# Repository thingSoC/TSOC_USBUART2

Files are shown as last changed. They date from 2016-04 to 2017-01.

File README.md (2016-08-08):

# TSOC_USBUART2

The thingSoC USBUART2 Base board incorporates a Cypress CY7C65215 Dual Channel USB Bridge, that supports UART, I2C, SPI, and JTAG interfaces in a thingSoC format.

The thingSoC USBUART2 Base board has two USB bridge channels, which can be programmed to be either UART, I2C, SPI, JTAG, or Capacitance Sensing (buttons/sliders) Human Input devices.

USB Bridge One (Port 1) is connected to an FTDI pinout compatible programming connector, while USB Bridge Two (Port 2) is connected to the thingSoC standard UART channel.

Port1 can be used to program a target microprocessor, at the same time Port2 is used for another purpose (i.e. debug channel, USB to RS-485 bridge, etc).  

It's like having two (2) FTDI adapters in One!

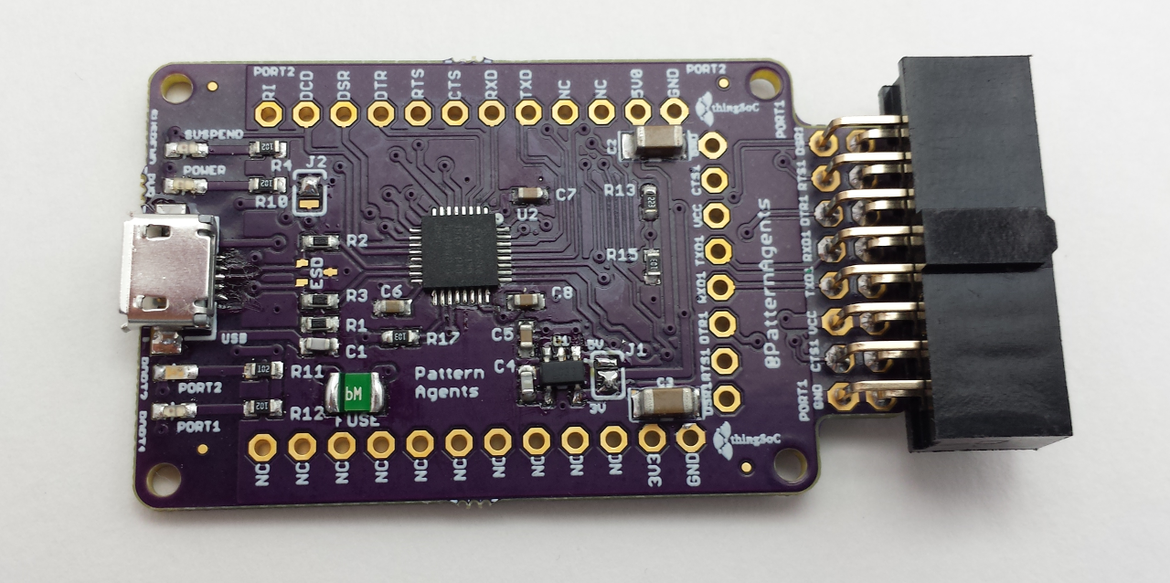
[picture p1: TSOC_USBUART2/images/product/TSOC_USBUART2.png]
thingSoC TSOC_USBUART2
[ 
TSOC_USBUART2](https://github.com/thingSoC/TSOC_USBUART2)

The thingSoC Digital Programming Connector (DPC) is backward compatible with 
the industry standard six (6) pin "FTDI" pinout USB to Serial Adapter pinout.
However, the thingSoC Digital Programming Connector (DPC) includes 
two(2) extra pins (RTS & DEBUG) for extended device programming, 
such as "NodeMCU types" which use the RTS signal as a programming Enable,
and the DTR signal as a programming Reset.

---------------------------------------
## Use it as a Programming Dongle

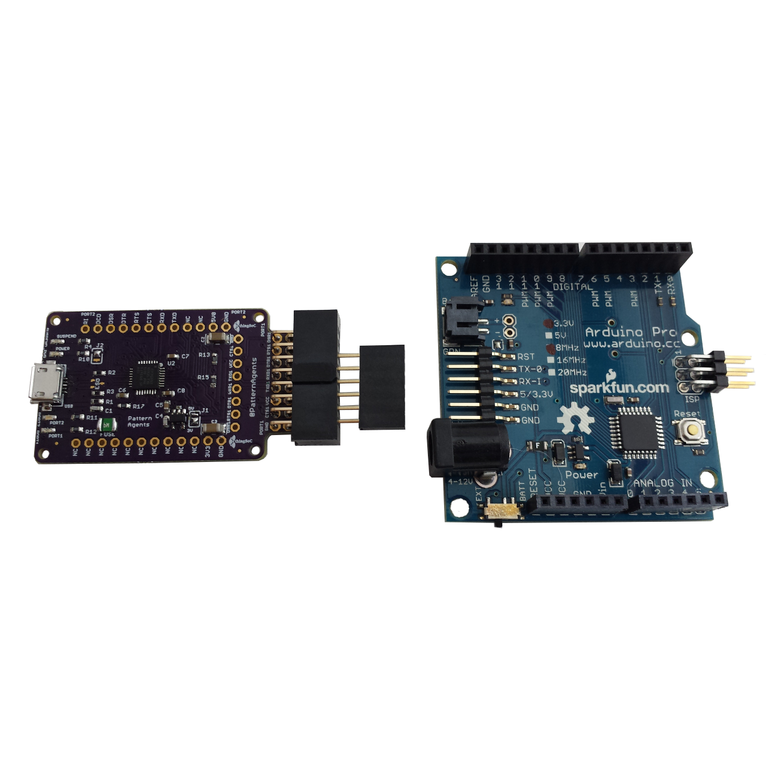
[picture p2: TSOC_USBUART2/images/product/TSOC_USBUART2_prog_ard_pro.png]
thingSoC TSOC_USBUART2
[ 
TSOC_USBUART2 to FTDI Six (6) Pin : Programming an Arduino Pro](https://github.com/thingSoC/TSOC_USBUART2)

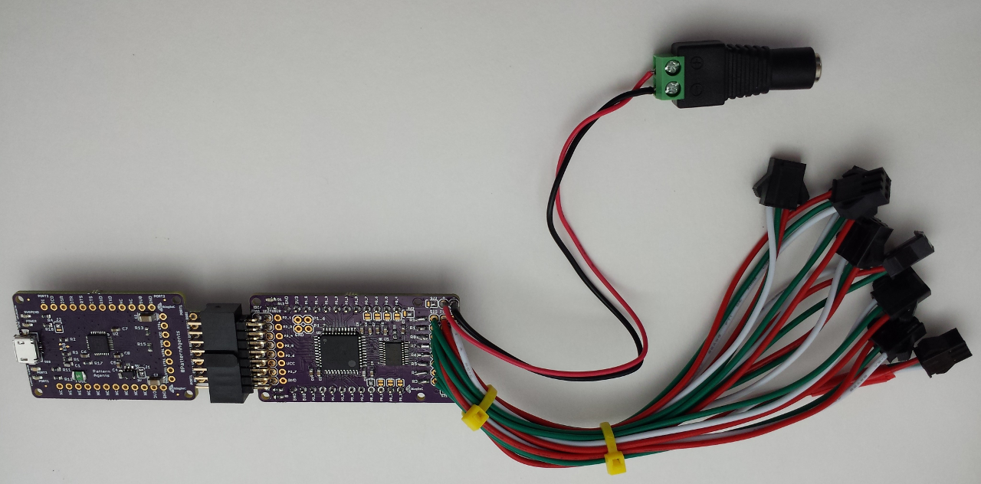
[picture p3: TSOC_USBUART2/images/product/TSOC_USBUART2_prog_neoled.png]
thingSoC TSOC_USBUART2
[ 
Programming a TSOC_NeoLED Board](https://github.com/thingSoC/TSOC_USBUART2)

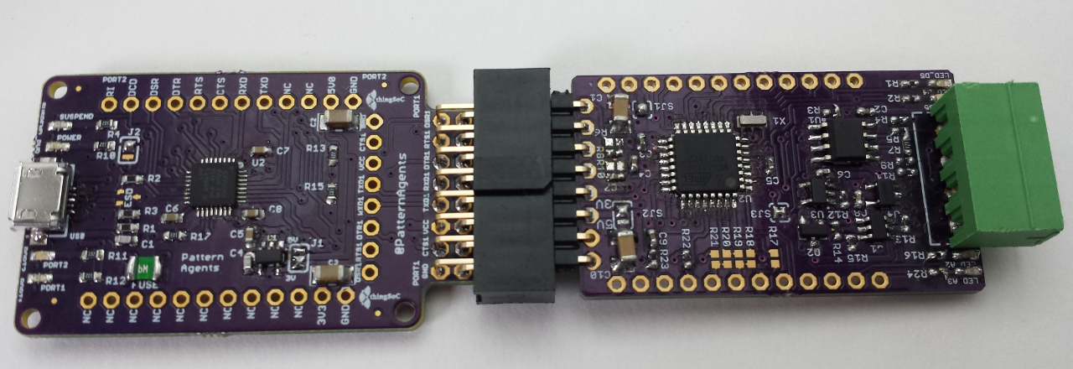
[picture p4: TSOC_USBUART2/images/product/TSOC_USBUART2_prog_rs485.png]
thingSoC TSOC_USBUART2
[ 
Programming a TSOC_RS485 Board](https://github.com/thingSoC/TSOC_USBUART2)

---------------------------------------
## Use it as a Protocol Adapter

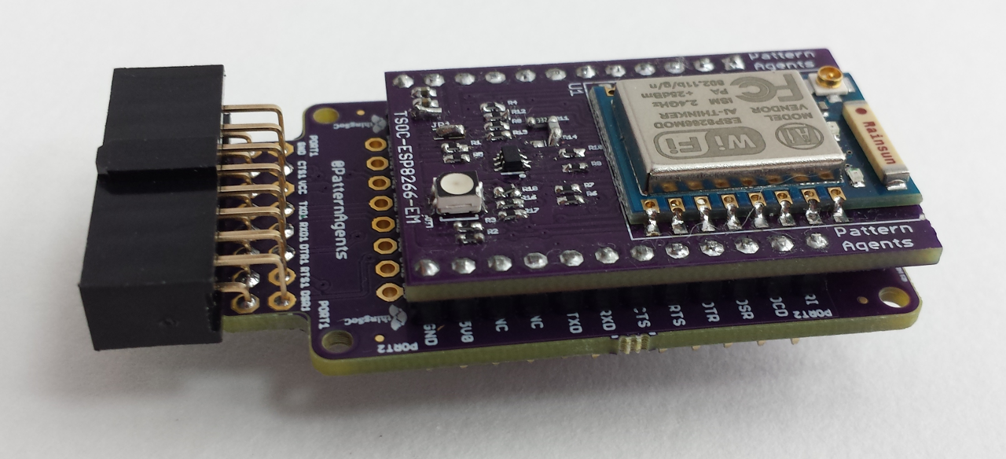
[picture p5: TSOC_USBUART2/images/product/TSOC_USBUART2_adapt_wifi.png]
thingSoC TSOC_USBUART2
[ 
USB to WiFi Adapter](https://github.com/thingSoC/TSOC_USBUART2)

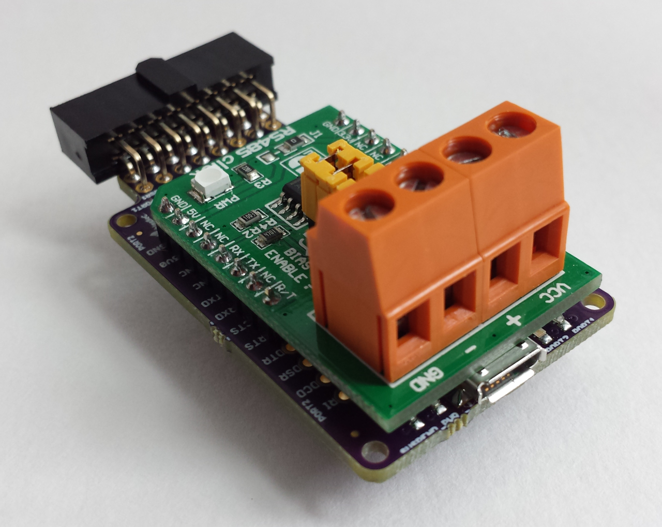
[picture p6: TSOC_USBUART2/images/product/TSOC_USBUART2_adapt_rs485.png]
thingSoC TSOC_USBUART2
[ 
USB to RS-485 Adapter](https://github.com/thingSoC/TSOC_USBUART2)

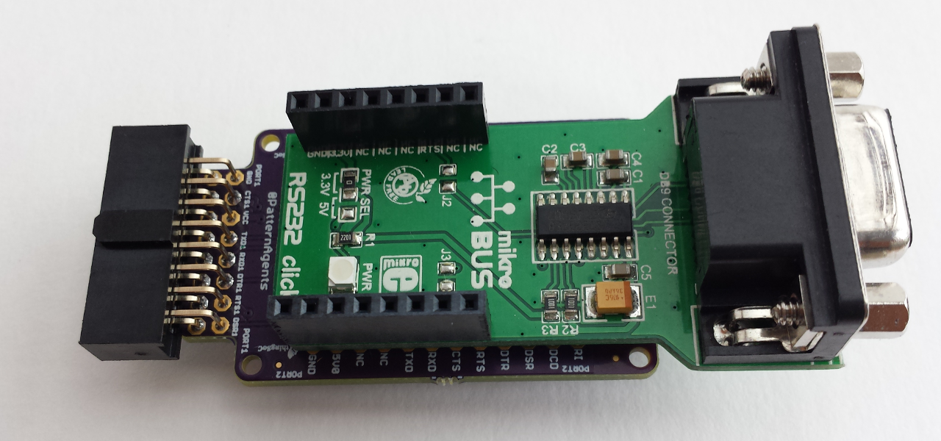
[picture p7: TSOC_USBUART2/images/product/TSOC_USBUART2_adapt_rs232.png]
thingSoC TSOC_USBUART2
[ 
USB to RS-232 Adapter](https://github.com/thingSoC/TSOC_USBUART2)

---------------------------------------
## TSOC_USBUART2 Model Images

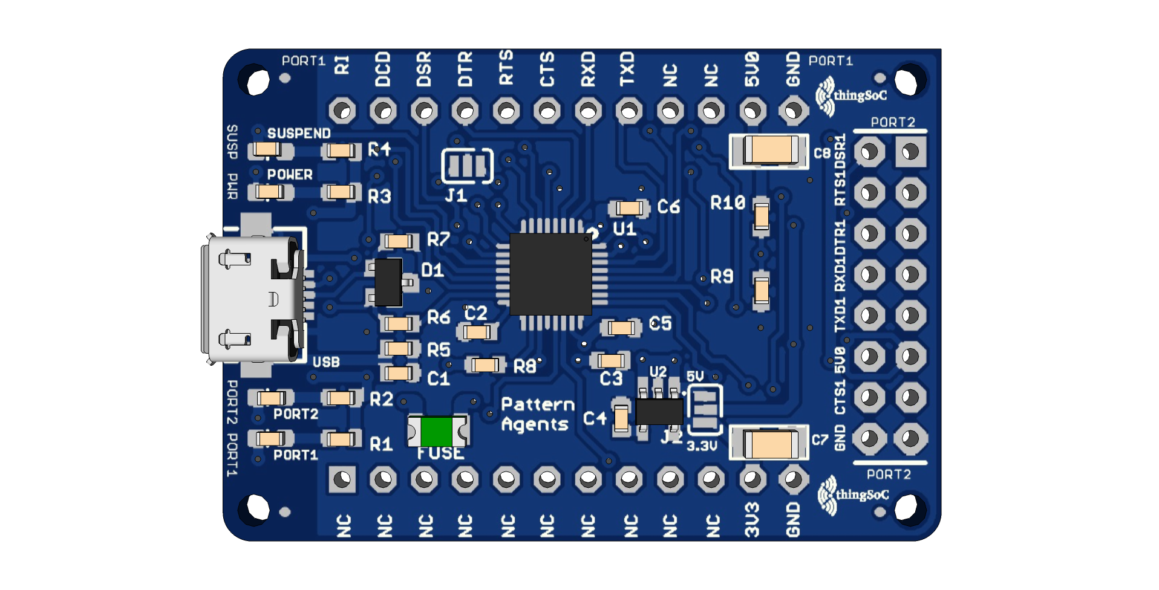
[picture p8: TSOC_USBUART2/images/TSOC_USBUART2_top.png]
thingSoC TSOC_USBUART2
[ 
TSOC_USBUART2](https://github.com/thingSoC/TSOC_USBUART2)

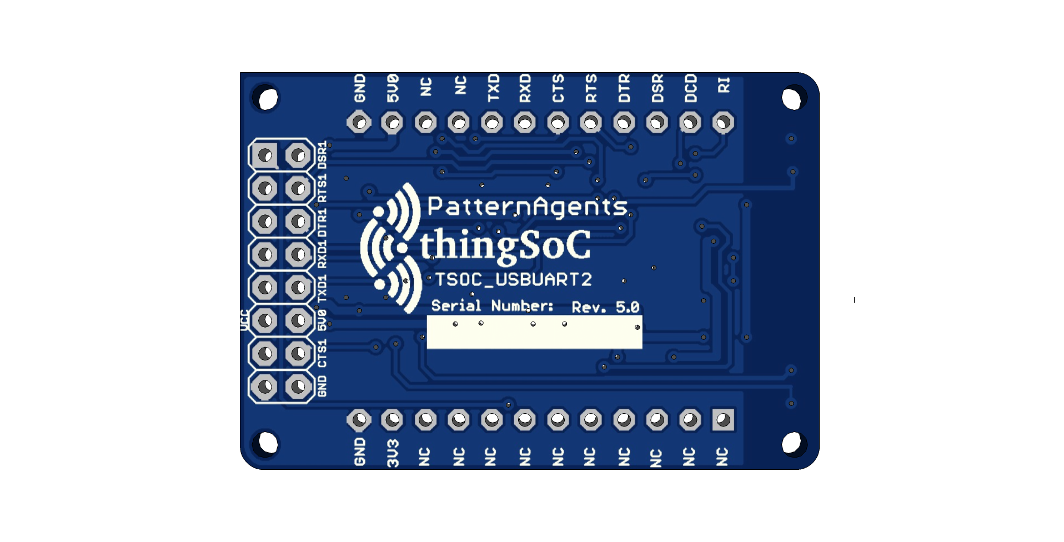
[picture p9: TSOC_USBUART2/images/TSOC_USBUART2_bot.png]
thingSoC TSOC_USBUART2
[ 
TSOC_USBUART2](https://github.com/thingSoC/TSOC_USBUART2)

---------------------------------------

## TSOC_USBUART2 Status <a name="TSOC_USBUART2_status"/>

Revision 1.0 - New Layout with Dual USB to UART device

Revision 2.0 - New PCB Outline, update to thingSoC Revision 2.0 

Revision 4.0 - New DPC connector, fix spacing.

Revision 4.1 - Update silkscreen, add more legends

---------------------------------------

## TSOC_USBUART2 Documentation Index <a name="TSOC_USBUART2_documentation_index"/>

[TSOC_USBUART2 Project](https://github.com/thingSoC/TSOC_USBUART2/)

[TSOC_USBUART2 Hardware](https://github.com/thingSoC/TSOC_USBUART2/tree/master/TSOC_USBUART2/hardware)

---------------------------------------

## thingSoC Documentation Index <a name="thingSoC_documentation_index"/>

[thingSoC Organization Website](http://thingSoC.github.io)

[thingSoC FAQ - Frequently Asked Questions](http://thingsoc.github.io/support/faq.html)

---------------------------------------

[thingSoC 
*thingSoC*](http://thingsoc.github.io)

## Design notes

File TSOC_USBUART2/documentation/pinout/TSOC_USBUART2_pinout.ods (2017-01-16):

 |  |  |  |  |  |  | USB
DEFAULT | PORT | ADC | PWM |  |  |  |  |  |  |  |  | DEFAULT | PORT | PWM | LEGEND
 |  |  |  |  |  |  |  |  |  |  |  |  |  |  | POWER/GROUND PINS
IO2 | NC |  |  |  |  |  |  |  |  |  |  | RI1 |  |  | DIGITAL PINS
IO1 | NC |  |  |  |  |  |  |  |  |  |  | DCD1 |  |  | ANALOG/ADC PINS
SS2 | NC |  |  |  |  |  |  |  |  |  |  | DSR1 |  |  | PWM PINS
SS1 | NC |  |  |  |  |  |  |  |  |  |  | DTR1 |  |  | TOUCH PINS
IRQ | NC |  |  |  |  |  |  |  |  |  |  | RTS1 |  |  | UART PINS
ATN | NC |  |  |  |  |  |  |  |  |  |  | CTS1 |  |  | JTAG/DEBUG PINS
SSEL | NC |  |  |  |  |  |  |  |  |  |  | RXD1 |  |  | I2C BUS PINS
SCK | NC |  |  |  |  |  |  |  |  |  |  | TXD1 |  |  | SPI BUS PINS
MISO | NC |  |  |  |  |  |  |  |  |  |  | NC
MOSI | NC |  |  |  |  |  |  |  |  |  |  | NC
3.3 VOLTS | 3V3 |  |  |  |  |  |  |  |  |  |  | 5.0 VOLTS | 5V0
GROUND | GND |  |  |  |  |  |  |  |  |  |  | GND | GND
 |  |  |  | DSR2 | RTS2 | DTR2 | TXD2 | RXD2 | 5V0 | CTS2 | GND |  |  | PatternAgents thingSoC USBUART2
 |  |  |  | NC | NC | NC | NC | NC | VCC | NC | GND |  |  | http://github.com/thingsoc/usbuart2

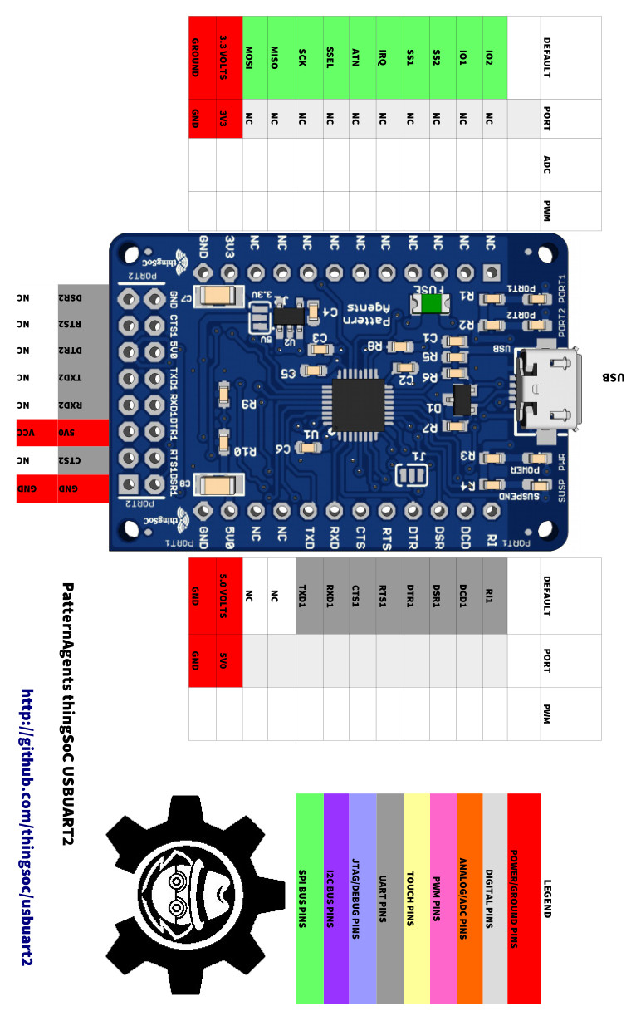
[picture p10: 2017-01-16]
TSOC_USBUART2/documentation/pinout/TSOC_USBUART2_pinout_long.jpg

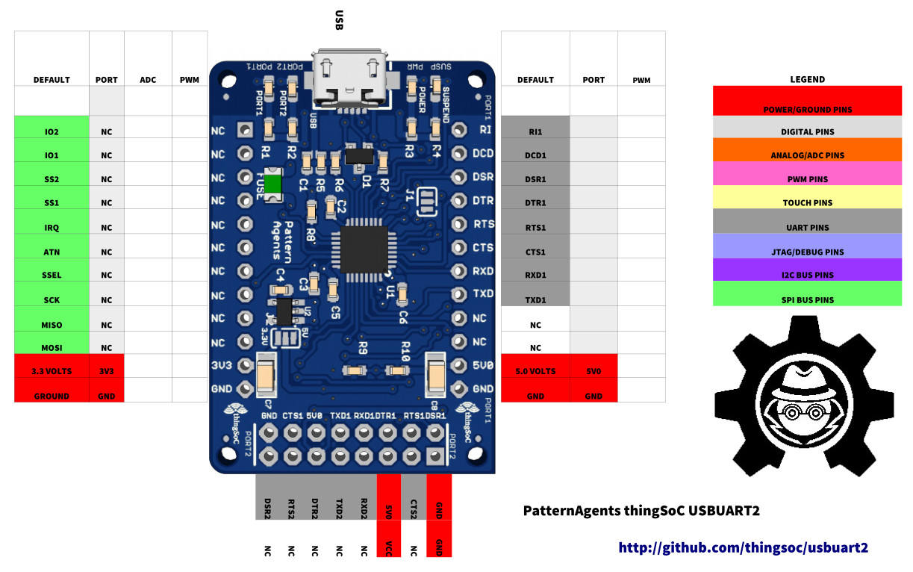
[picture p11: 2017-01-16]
TSOC_USBUART2/documentation/pinout/TSOC_USBUART2_pinout.jpg

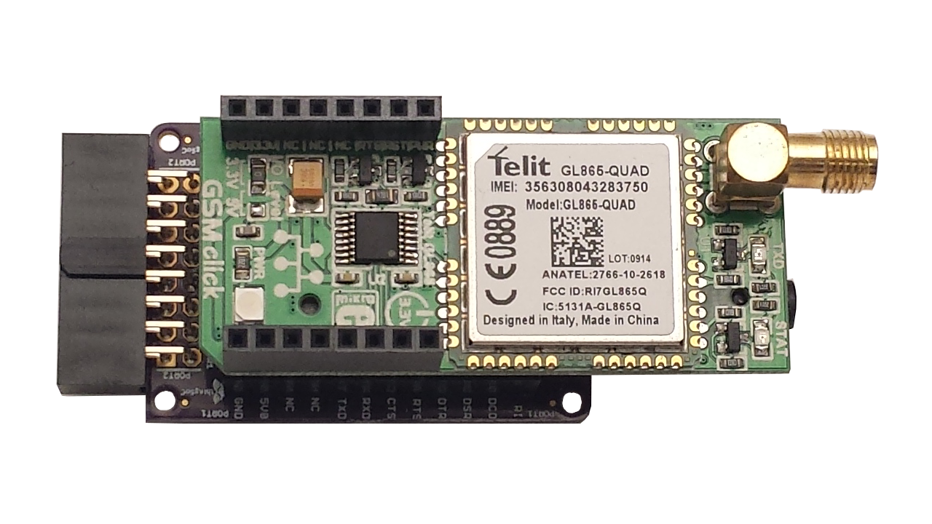
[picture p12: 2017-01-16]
TSOC_USBUART2/images/product/TSOC_USBUART2_with_GSM.png

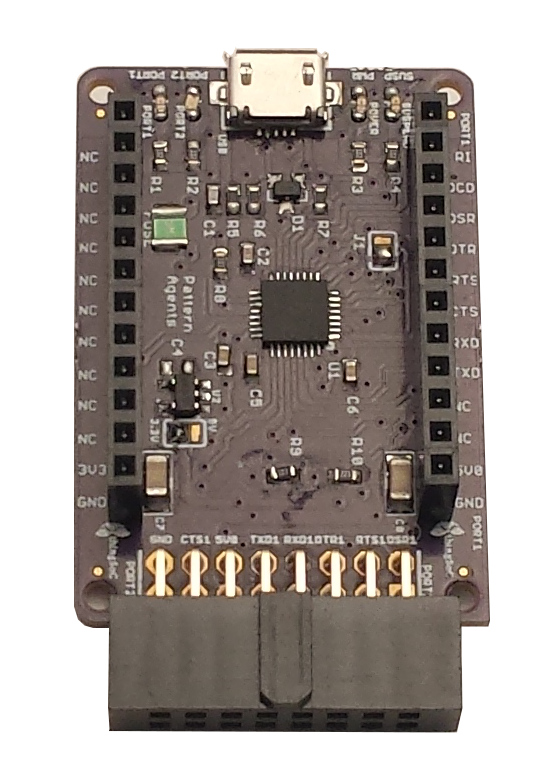
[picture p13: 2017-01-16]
TSOC_USBUART2/images/product/TSOC_UART_top_pop_vert.jpg

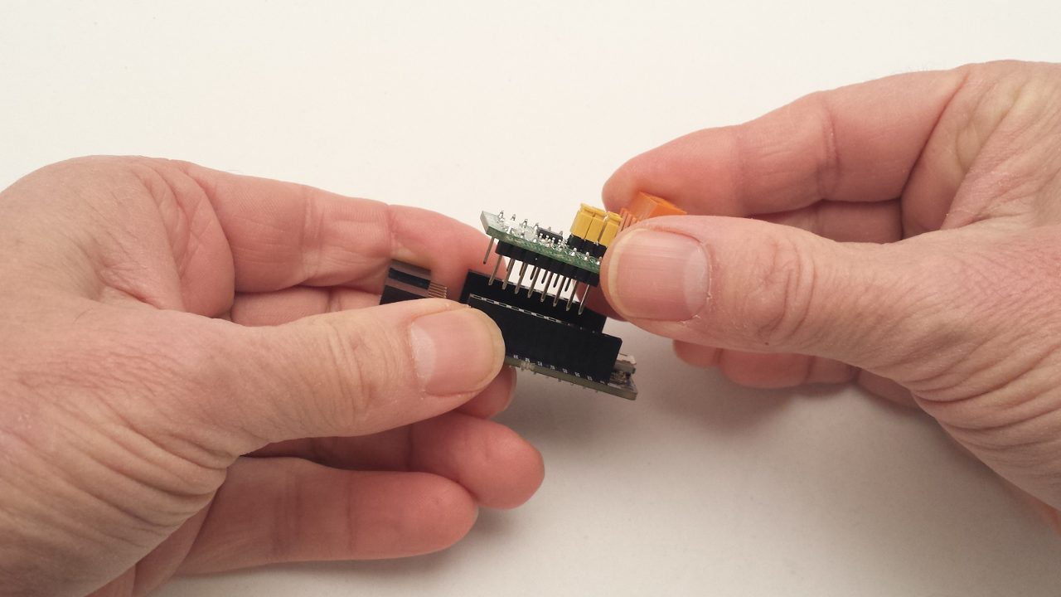
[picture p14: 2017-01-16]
TSOC_USBUART2/images/product/TSOC_USBUART2_adapt_rs485_insert.png

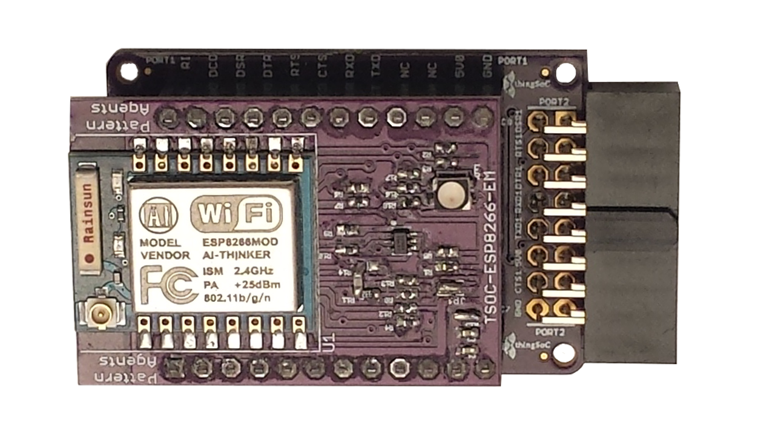
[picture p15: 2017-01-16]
TSOC_USBUART2/images/product/TSOC_USBUART2_with_ESP8266.png

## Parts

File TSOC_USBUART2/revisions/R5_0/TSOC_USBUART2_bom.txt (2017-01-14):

Partlist exported from U:/PatternAgents/eagle/TSOC_Modules/TSOC_USBUART2/TSOC_USBUART2/revisions/R5_0/TSOC_USBUART2.sch at 12/18/2016 3:53:13 PM

Part    Value              Device                         Package          Description                                                                                                   
C1      470pF              CAP-0603                       EIA-0603         Ceramic Capacitor SMD                                                                                         
C2      1.0uF              CAP-0603                       EIA-0603         Ceramic Capacitor SMD                                                                                         
C3      0.1uF              CAP-0603                       EIA-0603         Ceramic Capacitor SMD                                                                                         
C4      470pF              CAP-0603                       EIA-0603         Ceramic Capacitor SMD                                                                                         
C5      0.1uF              CAP-0603                       EIA-0603         Ceramic Capacitor SMD                                                                                         
C6      0.1uF              CAP-0603                       EIA-0603         Ceramic Capacitor SMD                                                                                         
C7      22uF               CAP-1206                       EIA-1206         Ceramic Capacitor SMD                                                                                         
C8      22uF               CAP-1206                       EIA-1206         Ceramic Capacitor SMD                                                                                         
D1      5V-225MW           SMD-DIODE-TVS-5V-225MW(SOT-23) SOT-23           304050003                                                                                                     
DPC                        M08X2                          2X8              .1" headers, two rows of 8 each                                                                               
FUSE    500mA-PTC          PTCSMD                         PTC-1206         Resettable Fuse PTC                                                                                           
PORT1   YELLOW             LED0603                        LED-0603         LEDs                                                                                                          
PORT2   BLUE               LED0603                        LED-0603         LEDs                                                                                                          
POWER   GRN                LED0603                        LED-0603         LEDs                                                                                                          
R1      1K                 RESISTOR-0603                  EIA-0603                                                                                                                       
R2      1K                 RESISTOR-0603                  EIA-0603                                                                                                                       
R3      1K                 RESISTOR-0603                  EIA-0603                                                                                                                       
R4      1K                 RESISTOR-0603                  EIA-0603                                                                                                                       
R5      1M                 RESISTOR-0603                  EIA-0603                                                                                                                       
R6      22                 RESISTOR-0603                  EIA-0603                                                                                                                       
R7      22                 RESISTOR-0603                  EIA-0603                                                                                                                       
R8      10K                RESISTOR-0603                  EIA-0603                                                                                                                       
R9      10K                RESISTOR-0603                  EIA-0603                                                                                                                       
R10     22K                RESISTOR-0603                  EIA-0603                                                                                                                       
SUSPEND RED                LED0603                        LED-0603         LEDs                                                                                                          
U1      CY7C65215-32-PROTO CY7C65215-32-PROTO             QFN32-PROTO      Cypress EZ-USB ® CY7C65215-32QFN                                       
U2      MIC5219 3.3V       V_REG_MIC52193.3V              SOT23-5          V_REG MIC5219                                                                                                 
USB     USB_AB             USB_AB                         USB-AB-MICRO-SMD USB

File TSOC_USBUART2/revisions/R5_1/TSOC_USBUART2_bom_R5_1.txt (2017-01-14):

Partlist exported from U:/PatternAgents/eagle/TSOC_Modules/TSOC_USBUART2/TSOC_USBUART2/revisions/R5_1/TSOC_USBUART2_R5_1.sch at 12/27/2016 11:35:59 AM

Qty Value              Device                          Package          Parts                  Description                                                                                                   
1   100pf              CERAMIC-100PF-50V-5%-NPO(0603)  C0603            C1                     302010076                                                                                                     
1   1uf                CERAMIC-1UF-25V-10%-X7R(0603)   C0603            C2                     302010139                                                                                                     
1   DNP                CAP-0603                        EIA-0603         C4                     Ceramic Capacitor SMD                                                                                         
3   100nf              CERAMIC-100NF-50V-10%-X7R(0603) C0603            C3, C5, C6             302010138                                                                                                     
2   22uf               TANTALUM-SMD-22UF-10V(AVX-A)    AVX-A            C7, C8                 302020008                                                                                                     
4   1K                 SMD-RES-1K-1%-1/10W(0603)       R0603            R1, R2, R3, R4         301010298                                                                                                     
1   1M                 SMD-RES-1M-1%-1/10W(0603)       R0603            R5                     301010151                                                                                                     
2   22R                SMD-RES-22R-5%-1/10W(0603)      R0603            R6, R7                 301010289                                                                                                     
2   10K                SMD-RES-10K-1%-1/10W(0603)      R0603            R8, R9                 301010299                                                                                                     
1   22K                SMD-RES-22K-5%-1/10W(0603)      R0603            R10                    301010132                                                                                                     
1   5V-225MW           SMD-DIODE-TVS-5V-225MW(SOT-23)  SOT-23           ESD                    304050003                                                                                                     
1   AP2112K-3.3V       V_REG_LDOSMD                    SOT23-5          U3                     Voltage Regulator LDO                                                                                         
1   BLUE-0603          SMD-LED-CLEAR-BLUE(0603)        LED-0603         D2                     304090045                                                                                                     
1   CY7C65215-32-PROTO CY7C65215-32-PROTO              QFN32-PROTO      U1                     Cypress EZ-USB ® CY7C65215-32QFN DUAL CHANNEL USB TO UART/SPI/IC Bridge                                       
1   GREEN-0603         SMD-LED-CLEAR-GREEN(0603)       LED-0603         D3                     304090043                                                                                                     
1   RED-0603           LED-SMD-RED-DIFFUSED(0603)      LED-0603         D4                     304090042                                                                                                     
1   SMD1206R500SF      SMD-PPTC-500MA(1206)            F1206            FUSE                   307010002                                                                                                     
1   USB_AB             USB_AB                          USB-AB-MICRO-SMD USB                     
1   YELLOW-0603        SMD-LED-CLEAR-YELLOW(0603)      LED-0603         D1                     304090044

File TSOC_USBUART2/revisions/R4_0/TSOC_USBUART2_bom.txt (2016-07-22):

Partlist exported from U:/PatternAgents/eagle/TSOC_Modules/TSOC_USBUART2/TSOC_USBUART2/TSOC_USBUART2.sch at 7/11/2016 12:24:20 PM

Qty Value              Device             Package              Parts                  Description                      Digikey              MPN
1   CY7C65215-32-PROTO CY7C65215-32-PROTO QFN32-PROTO          U2                     CY7C65215-32QFN
1   MIC5219 3.3V       V_REG_MIC52193.3V  SOT23-5              U1                     MIC5219
1   SP1001-02JTG       SP1001-02JTG       SC70-3               ESD                    TVS Diode Array
1   USB_AB             USB_AB             USB-AB-MICRO-SMD     USB                    USB-AB-MICRO-SMD
1   M08X02             M08X2              2X8                  J3                     .1" headers, Male, Shrouded, RA  ED10535-ND           On-Shore-Technology-Inc. 302-R161
2   M12                M12                1X12F                TSOC1, TSOC2           .1" headers, Female              S6100-ND               PPTC121LFBN-RC
1   M08                M08                1X08F                TSOC3                  .1" headers, Female              S7006-ND               PPTC081LFBN-RC
1   RED                LED0603            LED-0603             SUSPEND                LED
1   BLUE               LED0603            LED-0603             TXD                    LED
1   GRN                LED0603            LED-0603             POWER                  LED
1   YELLOW             LED0603            LED-0603             RXD                    LED
1   500mA-PTC          PTCSMD             PTC-1206             FUSE                   Fuse PPTC (0.5A @ 15v)
3   0.1uF              CAP-0603           EIA-0603             C5, C7, C8             Capacitor SMD
1   1.0uF              CAP-0603           EIA-0603             C6                     Capacitor SMD
2   10K                RESISTOR-0603      EIA-0603             R15, R17               Resistor SMD
4   1K                 RESISTOR-0603      EIA-0603             R4, R10, R11, R12      Resistor SMD
1   1M                 RESISTOR-0603      EIA-0603             R1                     Resistor SMD
2   22                 RESISTOR-0603      EIA-0603             R2, R3                 Resistor SMD
1   22K                RESISTOR-0603      EIA-0603             R13                    Resistor SMD
2   22uF               CAP-1206           EIA-1206             C2, C3                 Capacitor SMD
2   470pF              CAP-0603           EIA-0603             C1, C4                 Capacitor SMD

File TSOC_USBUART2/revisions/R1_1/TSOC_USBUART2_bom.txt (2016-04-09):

Partlist exported from /home/moxon/github/TSOC-USBUART2/TSOC-USBUART2/TSOC_USBUART2.sch at 4/9/16 11:58 AM
Qty Value              Device             Package          Parts                  Description
1   RED                LED0603            LED-0603         SUSPEND                LEDs                                                            
1   GRN                LED0603            LED-0603         POWER                  LEDs                                                                 
1   BLUE               LED0603            LED-0603         TXD                    LEDs                          
1   YELLOW             LED0603            LED-0603         RXD                    LEDs
3   0.1uF              CAP-0603           EIA-0603         C5, C7, C8             Ceramic Capacitor SMD
1   1.0uF              CAP-0603           EIA-0603         C6                     Ceramic Capacitor SMD
2   10K                RESISTOR-0603      EIA-0603         R15, R17                                   
1   1A                 FUSE               EIA-0603         F1                     Resettable PPTC Fuse - 0603 Footptint
4   1K                 RESISTOR-0603      EIA-0603         R4, R10, R11, R12                                          
1   1M                 RESISTOR-0603      EIA-0603         R1                                                        
2   22                 RESISTOR-0603      EIA-0603         R2, R3                                                   
1   22K                RESISTOR-0603      EIA-0603         R13                                                     
2   22uF               CAP-1206           EIA-1206         C2, C3                 Ceramic Capacitor SMD           
2   470pF              CAP-0603           EIA-0603         C1, C4                 Ceramic Capacitor SMD          
1   CY7C65215-32-PROTO CY7C65215-32-PROTO QFN32-PROTO      U2                     Cypress EZ-USB ® CY7C65215-32QFN DUAL CHANNEL USB TO UART/SPI/IC Bridge
1   M08                M08                1X08-SMD-FEMALE  P1                                                                                        
1   M08PTH             M08PTH             1X08             P1A                                                                                      
1   MIC5219 3.3V       V_REG_MIC52193.3V  SOT23-5          U1                     V_REG MIC5219                                                    
1   SP1001-02JTG       SP1001-02JTG       SC70-3           ESD                    Littelfuse SP1001-02JTG TVS Diode Array 8pf 15kV 
1   USB_AB             USB_AB             USB-AB-MICRO-SMD USB                    USB AB connector

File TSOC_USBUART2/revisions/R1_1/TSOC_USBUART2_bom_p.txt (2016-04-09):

Partlist exported from /home/moxon/github/TSOC-USBUART2/TSOC-USBUART2/TSOC_USBUART2.sch at 4/9/16 11:56 AM

Part    Value              Device             Package          Description                                                                                                                                                                               
C1      470pF              CAP-0603           EIA-0603         Ceramic Capacitor SMD                                                                                                                                                                     
C2      22uF               CAP-1206           EIA-1206         Ceramic Capacitor SMD                                                                                                                                                                     
C3      22uF               CAP-1206           EIA-1206         Ceramic Capacitor SMD                                                                                                                                                                     
C4      470pF              CAP-0603           EIA-0603         Ceramic Capacitor SMD                                                                                                                                                                     
C5      0.1uF              CAP-0603           EIA-0603         Ceramic Capacitor SMD                                                                                                                                                                     
C6      1.0uF              CAP-0603           EIA-0603         Ceramic Capacitor SMD                                                                                                                                                                     
C7      0.1uF              CAP-0603           EIA-0603         Ceramic Capacitor SMD                                                                                                                                                                     
C8      0.1uF              CAP-0603           EIA-0603         Ceramic Capacitor SMD                                                                                                                                                                     
ESD     SP1001-02JTG       SP1001-02JTG       SC70-3           Littelfuse SP1001-02JTG 
F1      1A                 FUSE               EIA-0603         Resettable PPTC Fuse - 0603 Footptint                                                                                                                                                                                                                                                                                                                 
J1      JMP-3-1_2          JMP-3-1_2          JMP-3-1_2        Three Terminal Jumper - 1 & 2 Connected                                                                                                                                                   
J2      JMP-3-1_2          JMP-3-1_2          JMP-3-1_2        Three Terminal Jumper - 1 & 2 Connected                                                                                                                                                   
P1      M08                M08                1X08-SMD-FEMALE                                                                                                                                                                                            
P1A     M08PTH             M08PTH             1X08                                                                                                                                                                                                       
POWER   GRN                LED0603            LED-0603         LEDs                                                                                                                                                                                      
R1      1M                 RESISTOR-0603      EIA-0603                                                                                                                                                                                                   
R2      22                 RESISTOR-0603      EIA-0603                                                                                                                                                                                                   
R3      22                 RESISTOR-0603      EIA-0603                                                                                                                                                                                                   
R4      1K                 RESISTOR-0603      EIA-0603                                                                                                                                                                                                   
R10     1K                 RESISTOR-0603      EIA-0603                                                                                                                                                                                                   
R11     1K                 RESISTOR-0603      EIA-0603                                                                                                                                                                                                   
R12     1K                 RESISTOR-0603      EIA-0603                                                                                                                                                                                                   
R13     22K                RESISTOR-0603      EIA-0603                                                                                                                                                                                                   
R15     10K                RESISTOR-0603      EIA-0603                                                                                                                                                                                                   
R17     10K                RESISTOR-0603      EIA-0603                                                                                                                                                                                                   
RXD     YELLOW             LED0603            LED-0603         LEDs                                                                                                                                                                                      
SUSPEND RED                LED0603            LED-0603         LEDs                                                                                                                                                                                                                                                                                                                                             
TXD     BLUE               LED0603            LED-0603         LEDs                                                                                                                                                                                      
U1      MIC5219 3.3V       V_REG_MIC52193.3V  SOT23-5          V_REG MIC5219                                                                                                                                                                             
U2      CY7C65215-32-PROTO CY7C65215-32-PROTO QFN32-PROTO      Cypress EZ-USB ® CY7C65215-32QFN DUAL CHANNEL USB TO UART/SPI/IC Bridge                                                                                                                   
USB     USB_AB             USB_AB             USB-AB-MICRO-SMD USB AB connector

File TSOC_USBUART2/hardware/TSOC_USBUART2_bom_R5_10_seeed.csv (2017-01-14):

Part/Designator | Manufacture Part Number/Seeed SKU | Quantity
C1, C2, C3, C4, C6, C7 | 302010138 | 6
R8, R9, R10, R11 | 301010299 | 4
R1 | 301010298 | 1
R2, R3, R4, R5, R6, R7, R12, R13, R14, R15 | 301010124 | 10
C5 | 302010013 | 1
I2C1, I2C2, I2C3, I2C4 | 320110034 | 4
I2CS | "320110033" | 1
J1 | 320020079 | 1
U1 | PCA9546APWR | 1
D1 | 304090043 | 1

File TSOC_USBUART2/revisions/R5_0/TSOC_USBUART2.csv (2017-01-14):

Part | Value | Device | Package | Description
$$U$2 | TSOC-LOGO | TSOC-LOGO | TSOC-LOGO-BLANK | thingSoC Logo
C1 | 470pF | CAP-0603 | EIA-0603 | Ceramic Capacitor SMD
C2 | 1.0uF | CAP-0603 | EIA-0603 | Ceramic Capacitor SMD
C3 | 0.1uF | CAP-0603 | EIA-0603 | Ceramic Capacitor SMD
C4 | 470pF | CAP-0603 | EIA-0603 | Ceramic Capacitor SMD
C5 | 0.1uF | CAP-0603 | EIA-0603 | Ceramic Capacitor SMD
C6 | 0.1uF | CAP-0603 | EIA-0603 | Ceramic Capacitor SMD
C7 | 22uF | CAP-1206 | EIA-1206 | Ceramic Capacitor SMD
C8 | 22uF | CAP-1206 | EIA-1206 | Ceramic Capacitor SMD
D1 | 5V-225MW | SMD-DIODE-TVS-5V-225MW(SOT-23) | SOT-23 | 304050003
DPC |  | M08X2 | 2X8 | .1 headers, two rows of 8 each"
FID1 | FIDUCIALUFIDUCIAL | FIDUCIALUFIDUCIAL | MICRO-FIDUCIAL | Fiducial Alignment Points
FID2 | FIDUCIALUFIDUCIAL | FIDUCIALUFIDUCIAL | MICRO-FIDUCIAL | Fiducial Alignment Points
FID3 | FIDUCIALUFIDUCIAL | FIDUCIALUFIDUCIAL | MICRO-FIDUCIAL | Fiducial Alignment Points
FID4 | FIDUCIALUFIDUCIAL | FIDUCIALUFIDUCIAL | MICRO-FIDUCIAL | Fiducial Alignment Points
FUSE | 500mA-PTC | PTCSMD | PTC-1206 | Resettable Fuse PTC
J1 | JMP-3-1_2 | JMP-3-1_2 | JMP-3-1_2 | Three Terminal Jumper - 1 & 2 Connected
J2 | JMP-3-1_2 | JMP-3-1_2 | JMP-3-1_2 | Three Terminal Jumper - 1 & 2 Connected
PORT1 | YELLOW | LED0603 | LED-0603 | LEDs
PORT2 | BLUE | LED0603 | LED-0603 | LEDs
POWER | GRN | LED0603 | LED-0603 | LEDs
R1 | 1K | RESISTOR-0603 | EIA-0603
R2 | 1K | RESISTOR-0603 | EIA-0603
R3 | 1K | RESISTOR-0603 | EIA-0603
R4 | 1K | RESISTOR-0603 | EIA-0603
R5 | 1M | RESISTOR-0603 | EIA-0603
R6 | 22 | RESISTOR-0603 | EIA-0603
R7 | 22 | RESISTOR-0603 | EIA-0603
R8 | 10K | RESISTOR-0603 | EIA-0603
R9 | 10K | RESISTOR-0603 | EIA-0603
R10 | 22K | RESISTOR-0603 | EIA-0603
SUSPEND | RED | LED0603 | LED-0603 | LEDs
TSOC | TSOC-24-BB | TSOC-24-BB | TSOC-BB-S24 | thingSoC Twenty-Four(24) Pin Socket
U$1 | TSOC-LOGO | TSOC-LOGO | TSOC-LOGO-BLANK | thingSoC Logo
U$3 | TSOC-LOGO | TSOC-LOGO | TSOC-LOGO-BLANK | thingSoC Logo
U$4 | TSOC-PCB-SINGLE | TSOC-PCB-SINGLE | TSOC-BB-BRD-DIM | thingSoC PCB Outlines
U$6 | TSOC-LOGO-SMALL | TSOC-LOGO-SMALL | TSOC-LOGO-SML | thingSoC Logo
U$100 | TSOC-LOGO-LRG | TSOC-LOGO-LRG | TSOC-LOGO-LRG | thingSoC Logo
U1 | CY7C65215-32-PROTO | CY7C65215-32-PROTO | QFN32-PROTO | Cypress EZ-USB ® CY7C65215-32QFN DUAL CHANNEL USB TO UART/SPI/IC Bridge
U2 | MIC5219 3.3V | V_REG_MIC52193.3V | SOT23-5 | V_REG MIC5219
USB | USB_AB | USB_AB | USB-AB-MICRO-SMD | This is a USB AB connector that is compatible with USB OTG. i.e. this connector can serve as a host or device

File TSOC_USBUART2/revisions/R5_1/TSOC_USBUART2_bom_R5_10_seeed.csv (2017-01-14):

Part/Designator | Manufacture Part Number/Seeed SKU | Quantity
C1 | 302010076 | 1
C2 | 302010139 | 1
C3, C5, C6 | 302010138 | 3
C7,C8 | 302020008 | 2
R1, R2, R3, R4 | 301010298 | 4
R5 | 301010151 | 1
R6, R7 | 301010289 | 2
R8, R9 | 301010299 | 2
R10 | 301010132 | 1
U1 | CY7C65215A-32LTXI | 1
U2 | AP2112K-3.3TRG1 | 1
D1 | 304090044 | 1
D2 | 304090045 | 1
D3 | 304090043 | 1
D4 | 304090042 | 1
ESD | 304050003 | 1
FUSE | 307010002 | 1
USB | 10104111-0001LF | 1
PORT1L, PORT1R | PPTC121LFBN-RC | 2
PORT2 | SFH11-PBPC-D08-RA-BK | 1

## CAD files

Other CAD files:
TSOC_USBUART2/eagleUp/TSOC_USBUART2.skp

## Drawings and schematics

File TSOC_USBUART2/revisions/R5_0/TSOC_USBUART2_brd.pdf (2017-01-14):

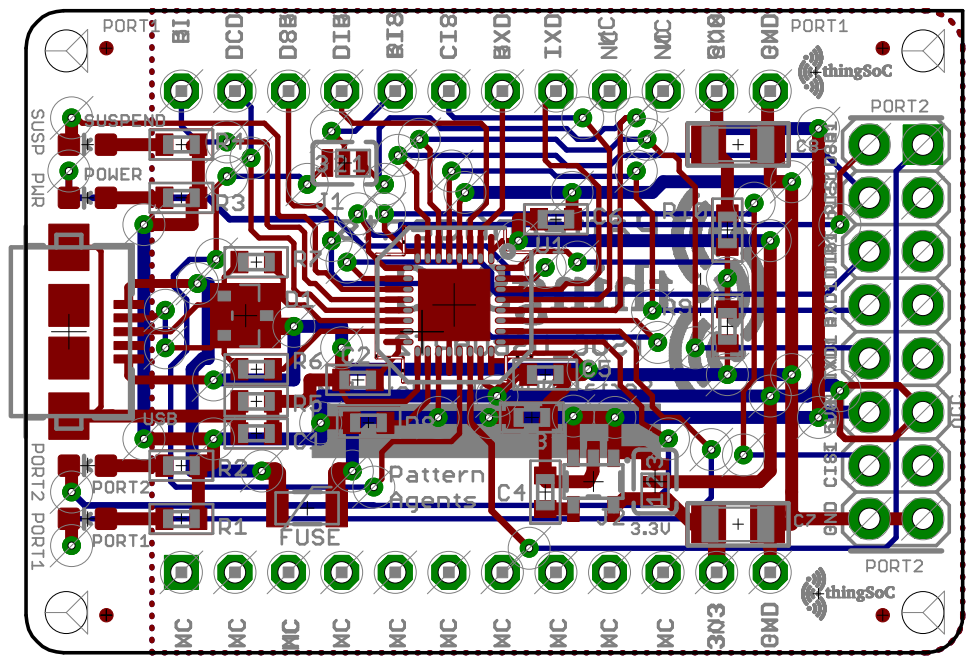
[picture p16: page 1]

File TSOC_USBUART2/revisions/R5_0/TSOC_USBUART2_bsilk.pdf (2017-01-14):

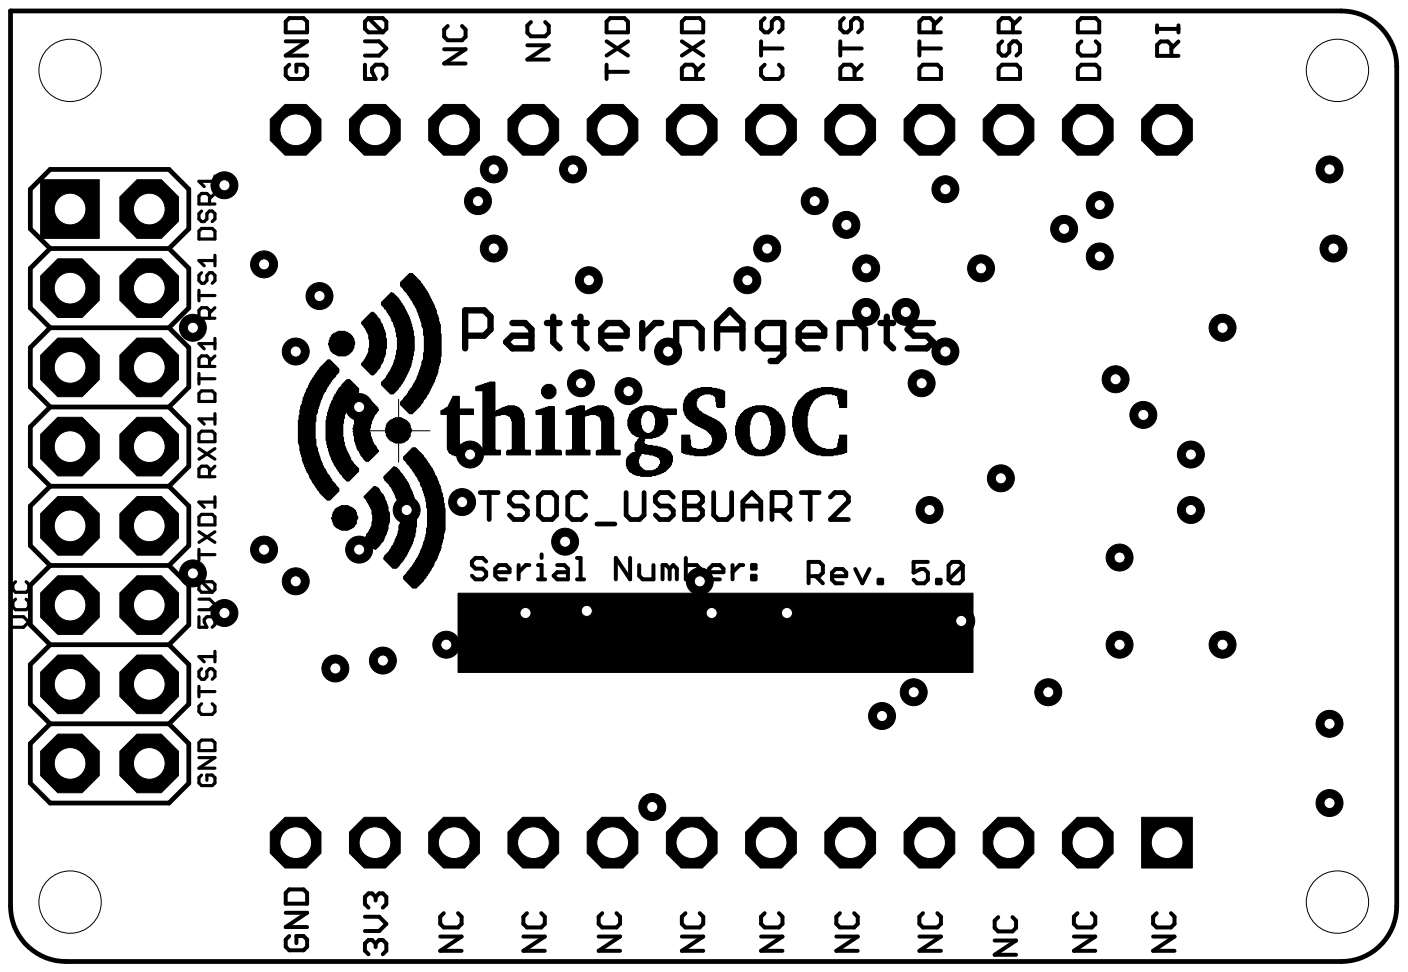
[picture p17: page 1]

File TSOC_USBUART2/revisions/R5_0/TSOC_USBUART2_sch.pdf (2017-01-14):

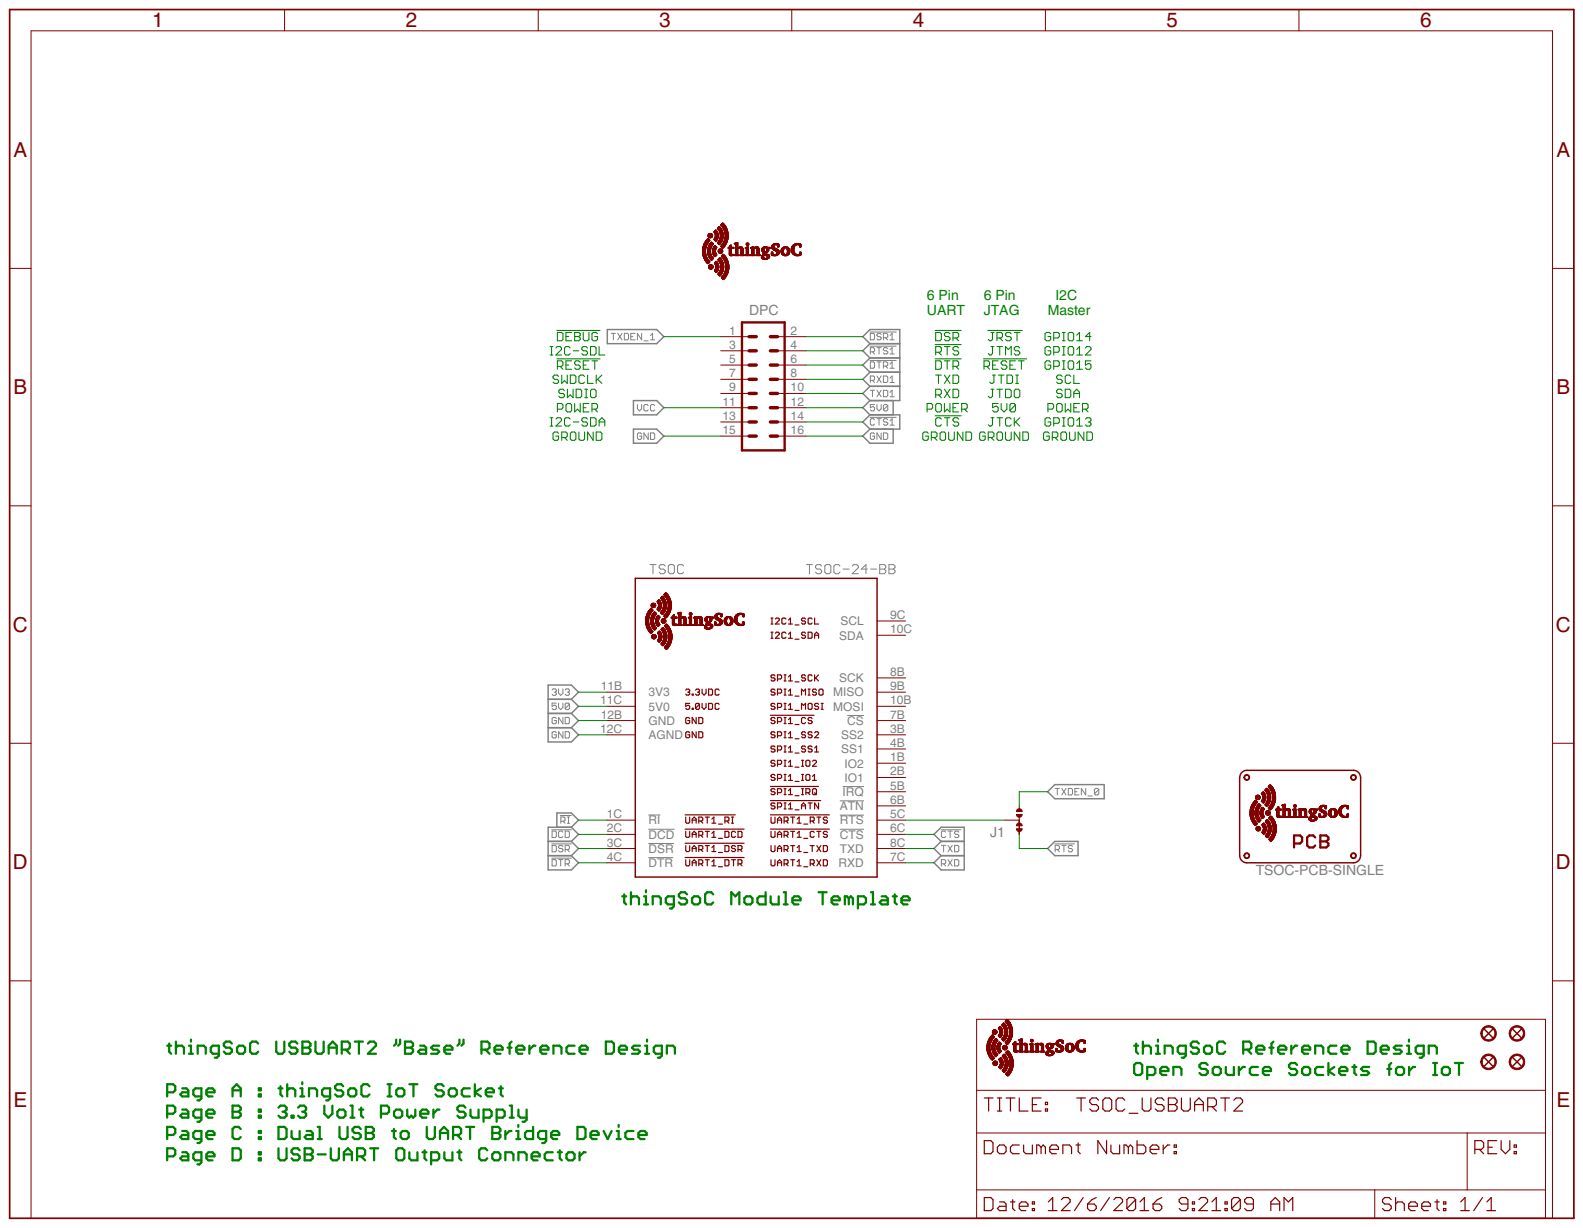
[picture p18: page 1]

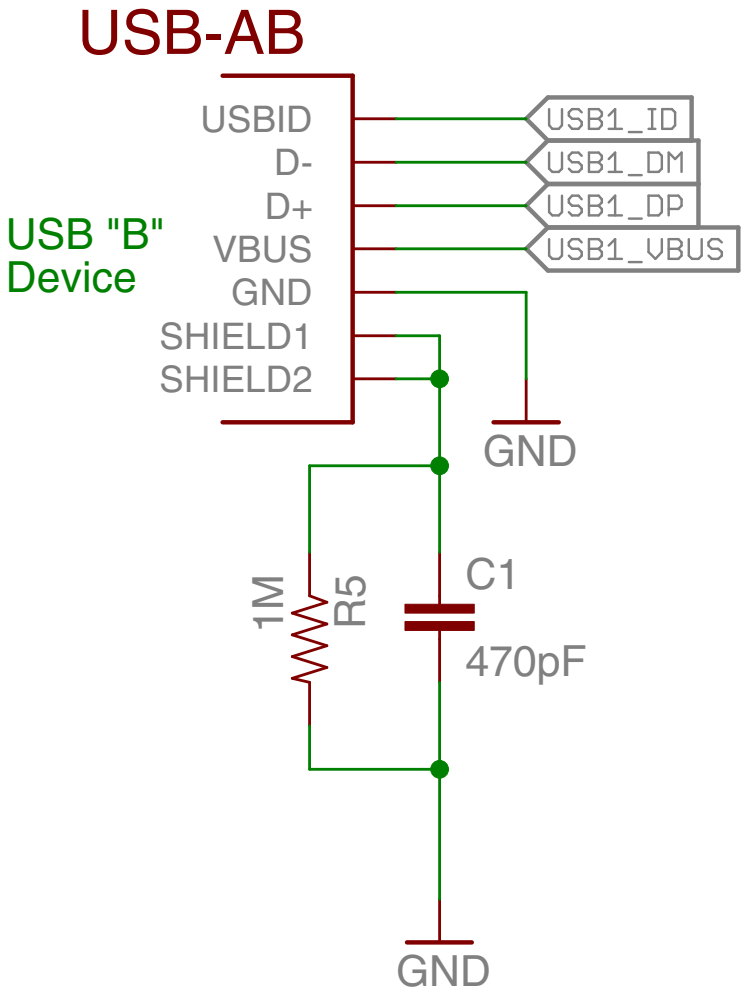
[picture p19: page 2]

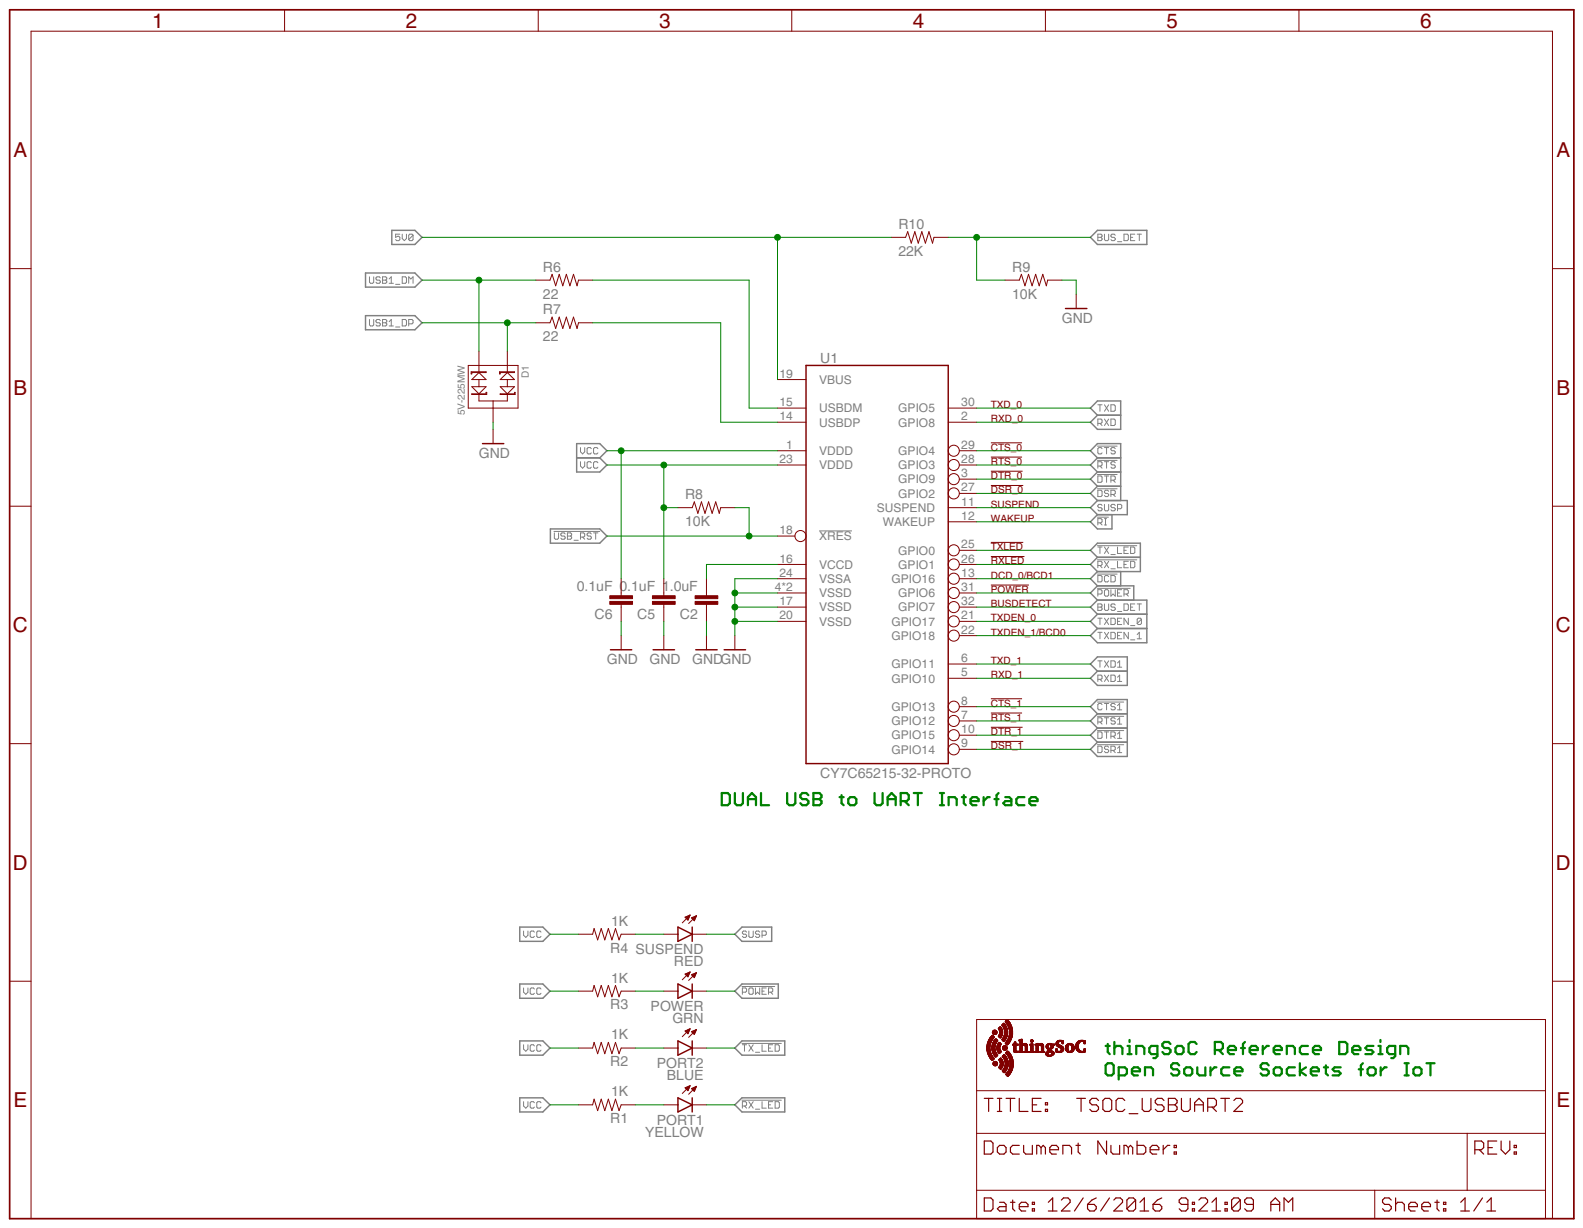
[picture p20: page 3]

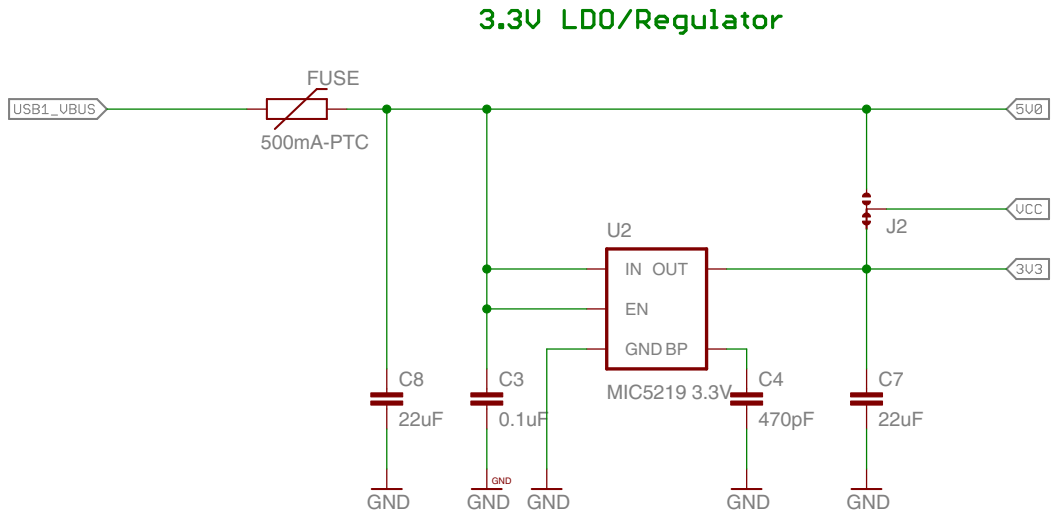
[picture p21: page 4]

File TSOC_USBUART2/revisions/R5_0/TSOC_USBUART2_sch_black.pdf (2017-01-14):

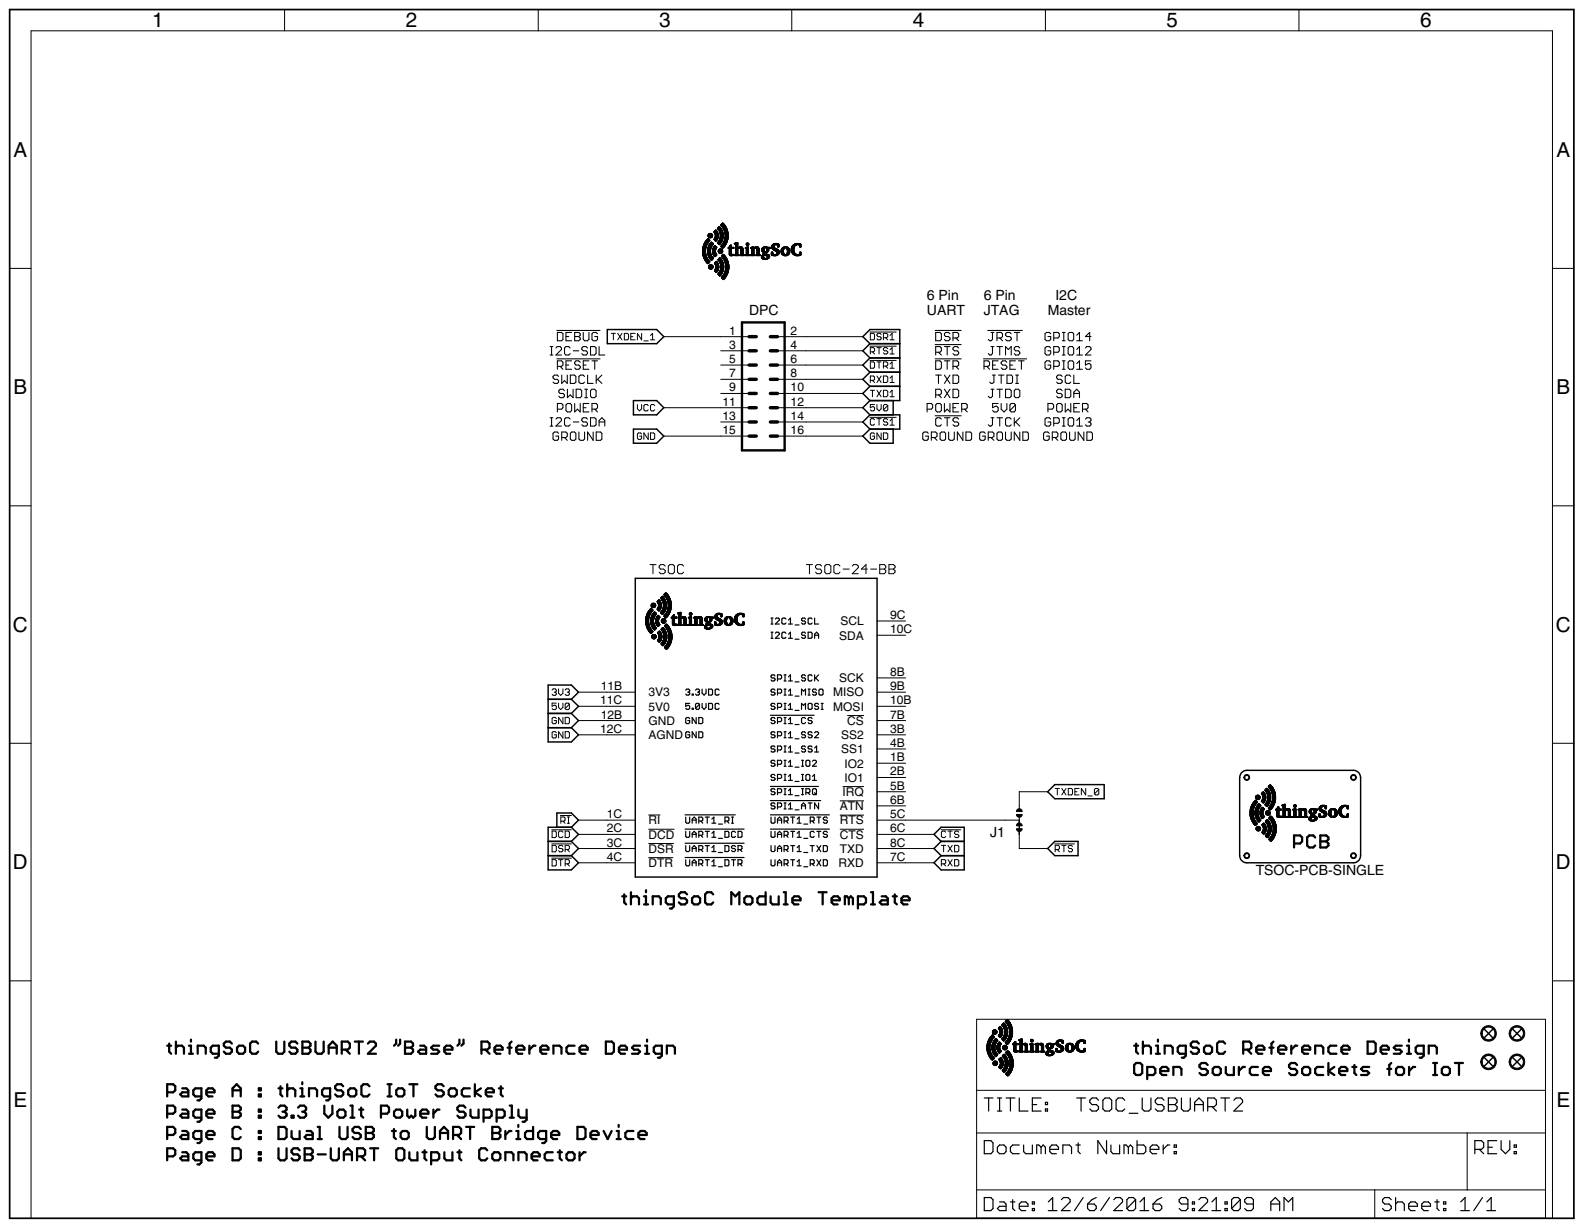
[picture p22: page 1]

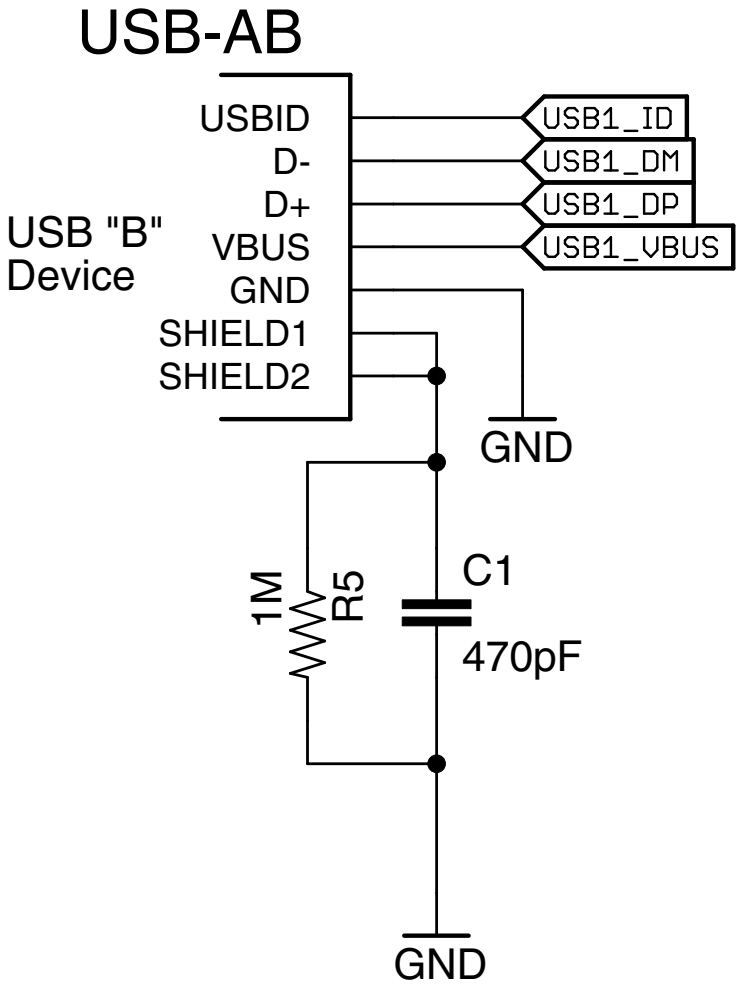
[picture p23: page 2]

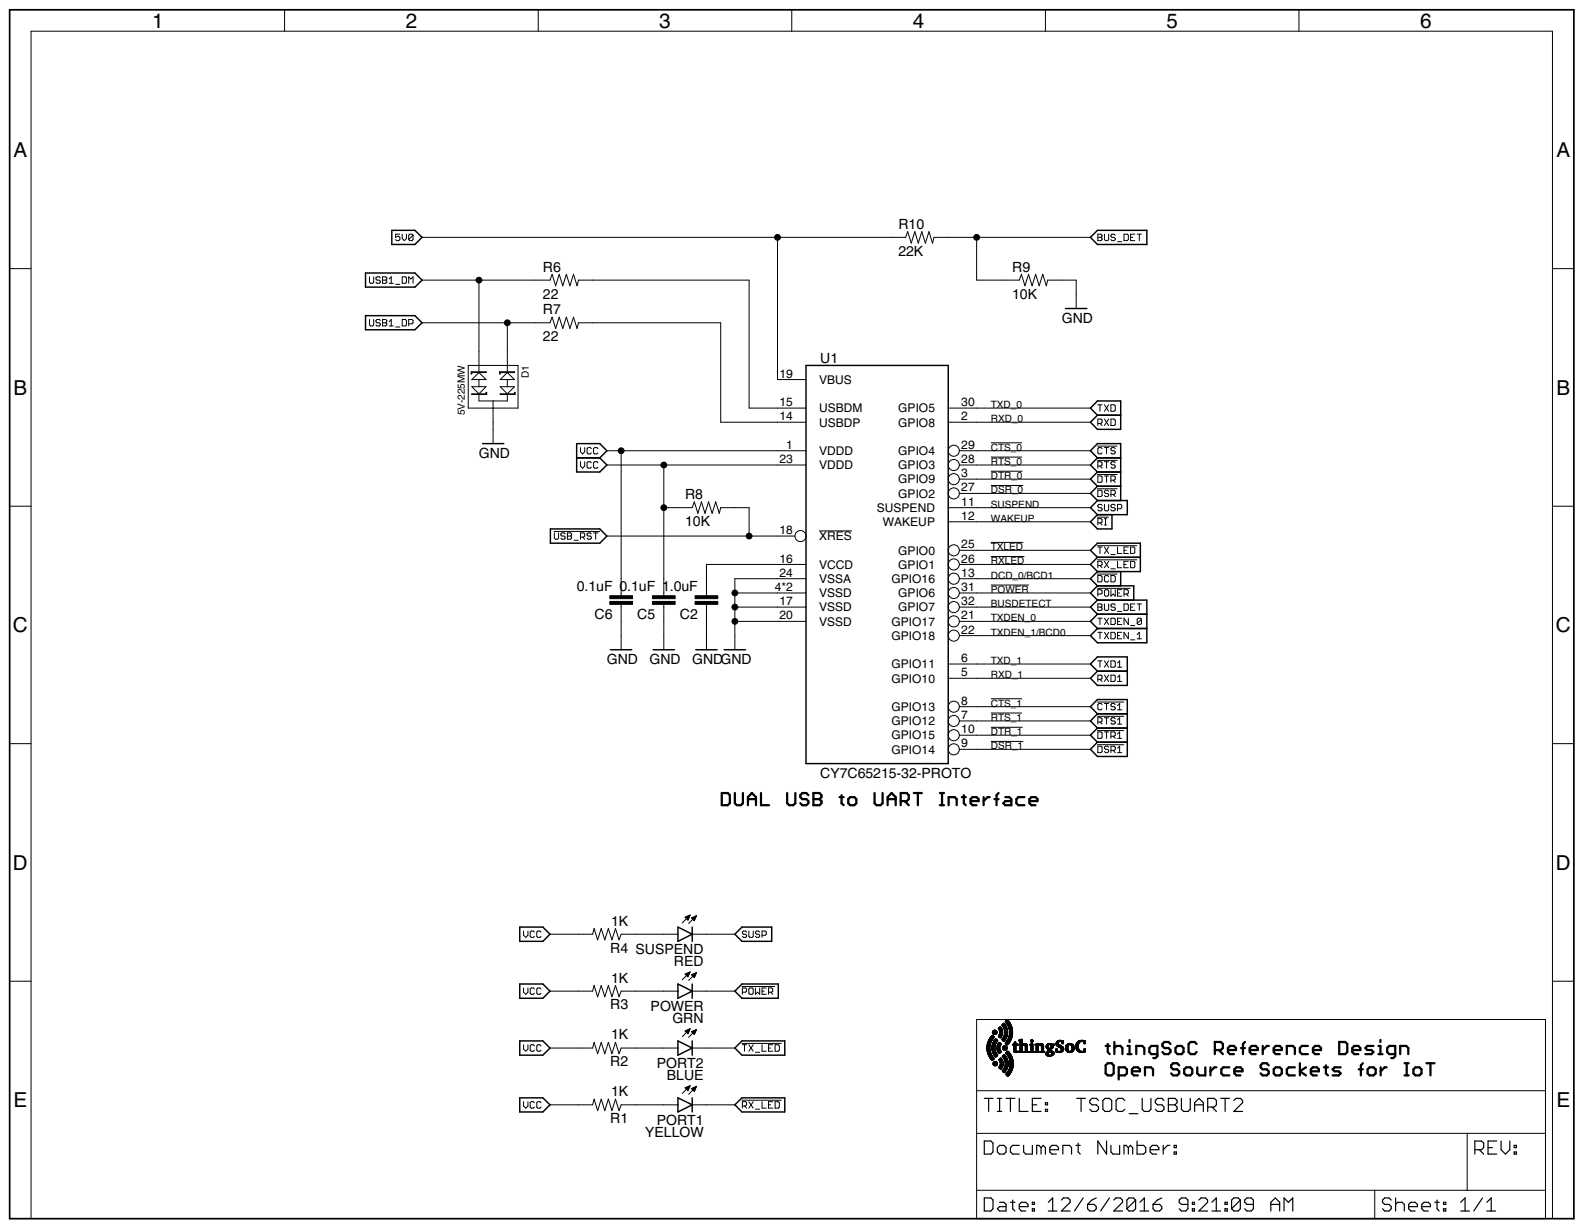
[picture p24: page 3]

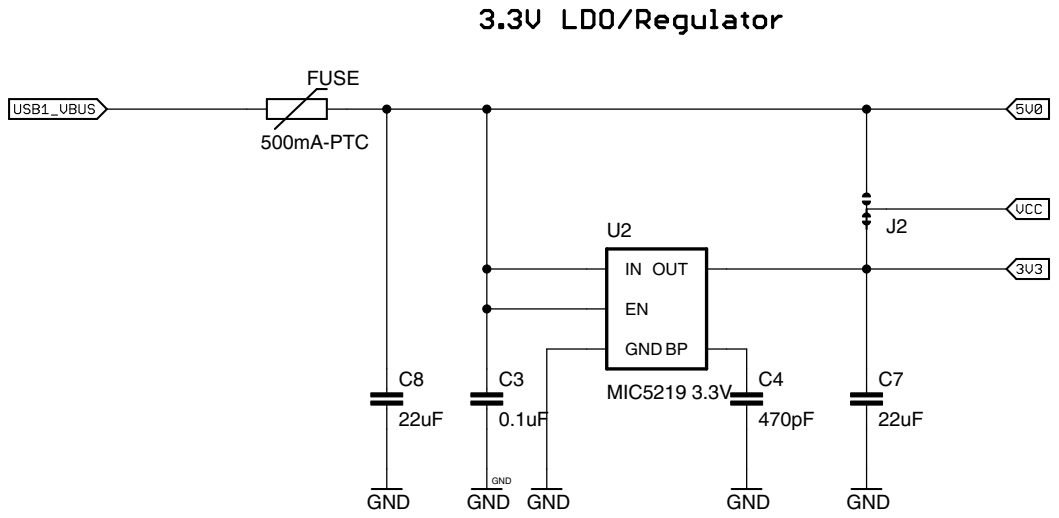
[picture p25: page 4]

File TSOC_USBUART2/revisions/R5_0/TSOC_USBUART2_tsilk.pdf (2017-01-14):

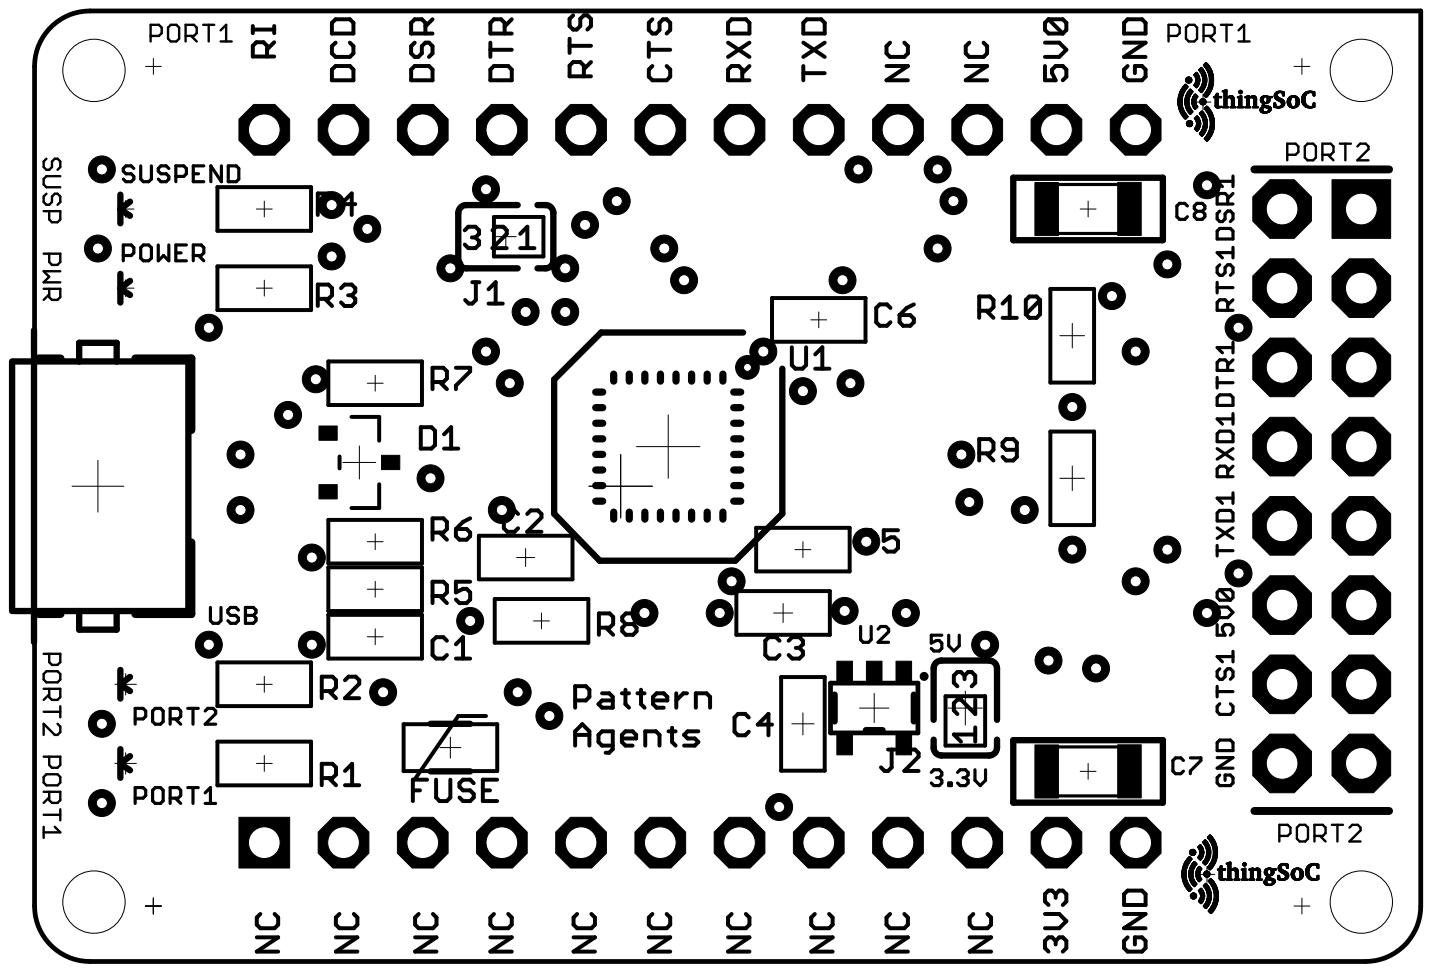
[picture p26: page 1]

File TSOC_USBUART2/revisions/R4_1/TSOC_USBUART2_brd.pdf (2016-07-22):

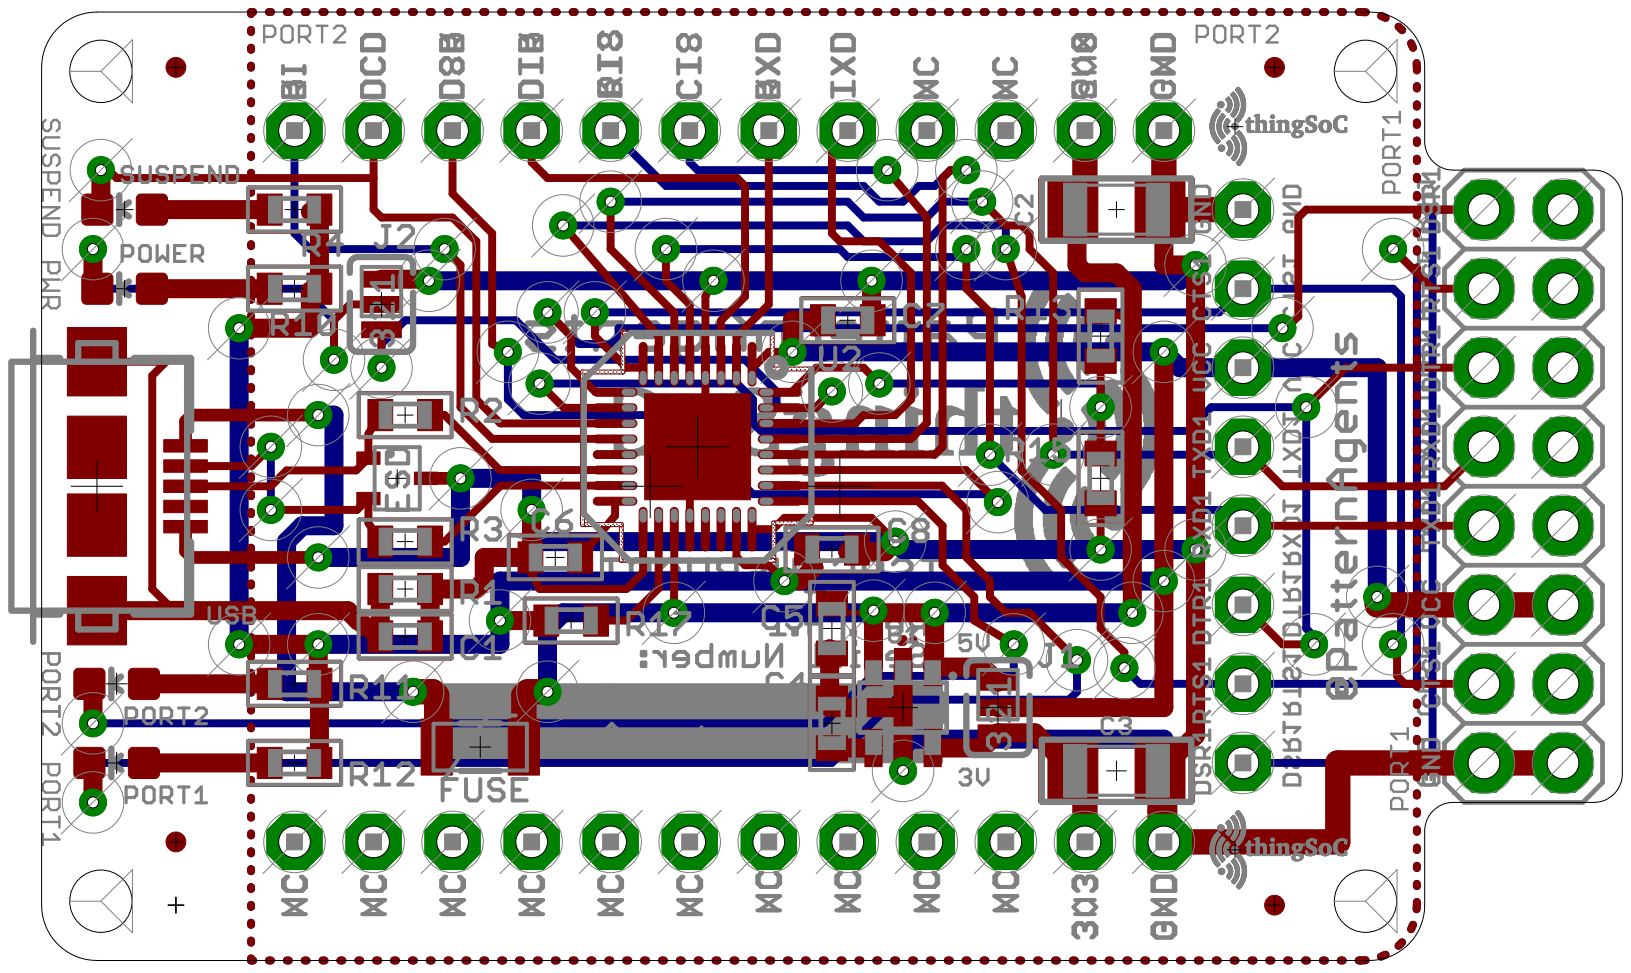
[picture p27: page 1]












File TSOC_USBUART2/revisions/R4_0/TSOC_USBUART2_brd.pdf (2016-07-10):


7/10/16 2:46 PM /data/customers/PatternAgents/eagle/TSOC_Modules/TSOC_USBUART2/TSOC_USBUART2/TSOC_USBUART2.brd

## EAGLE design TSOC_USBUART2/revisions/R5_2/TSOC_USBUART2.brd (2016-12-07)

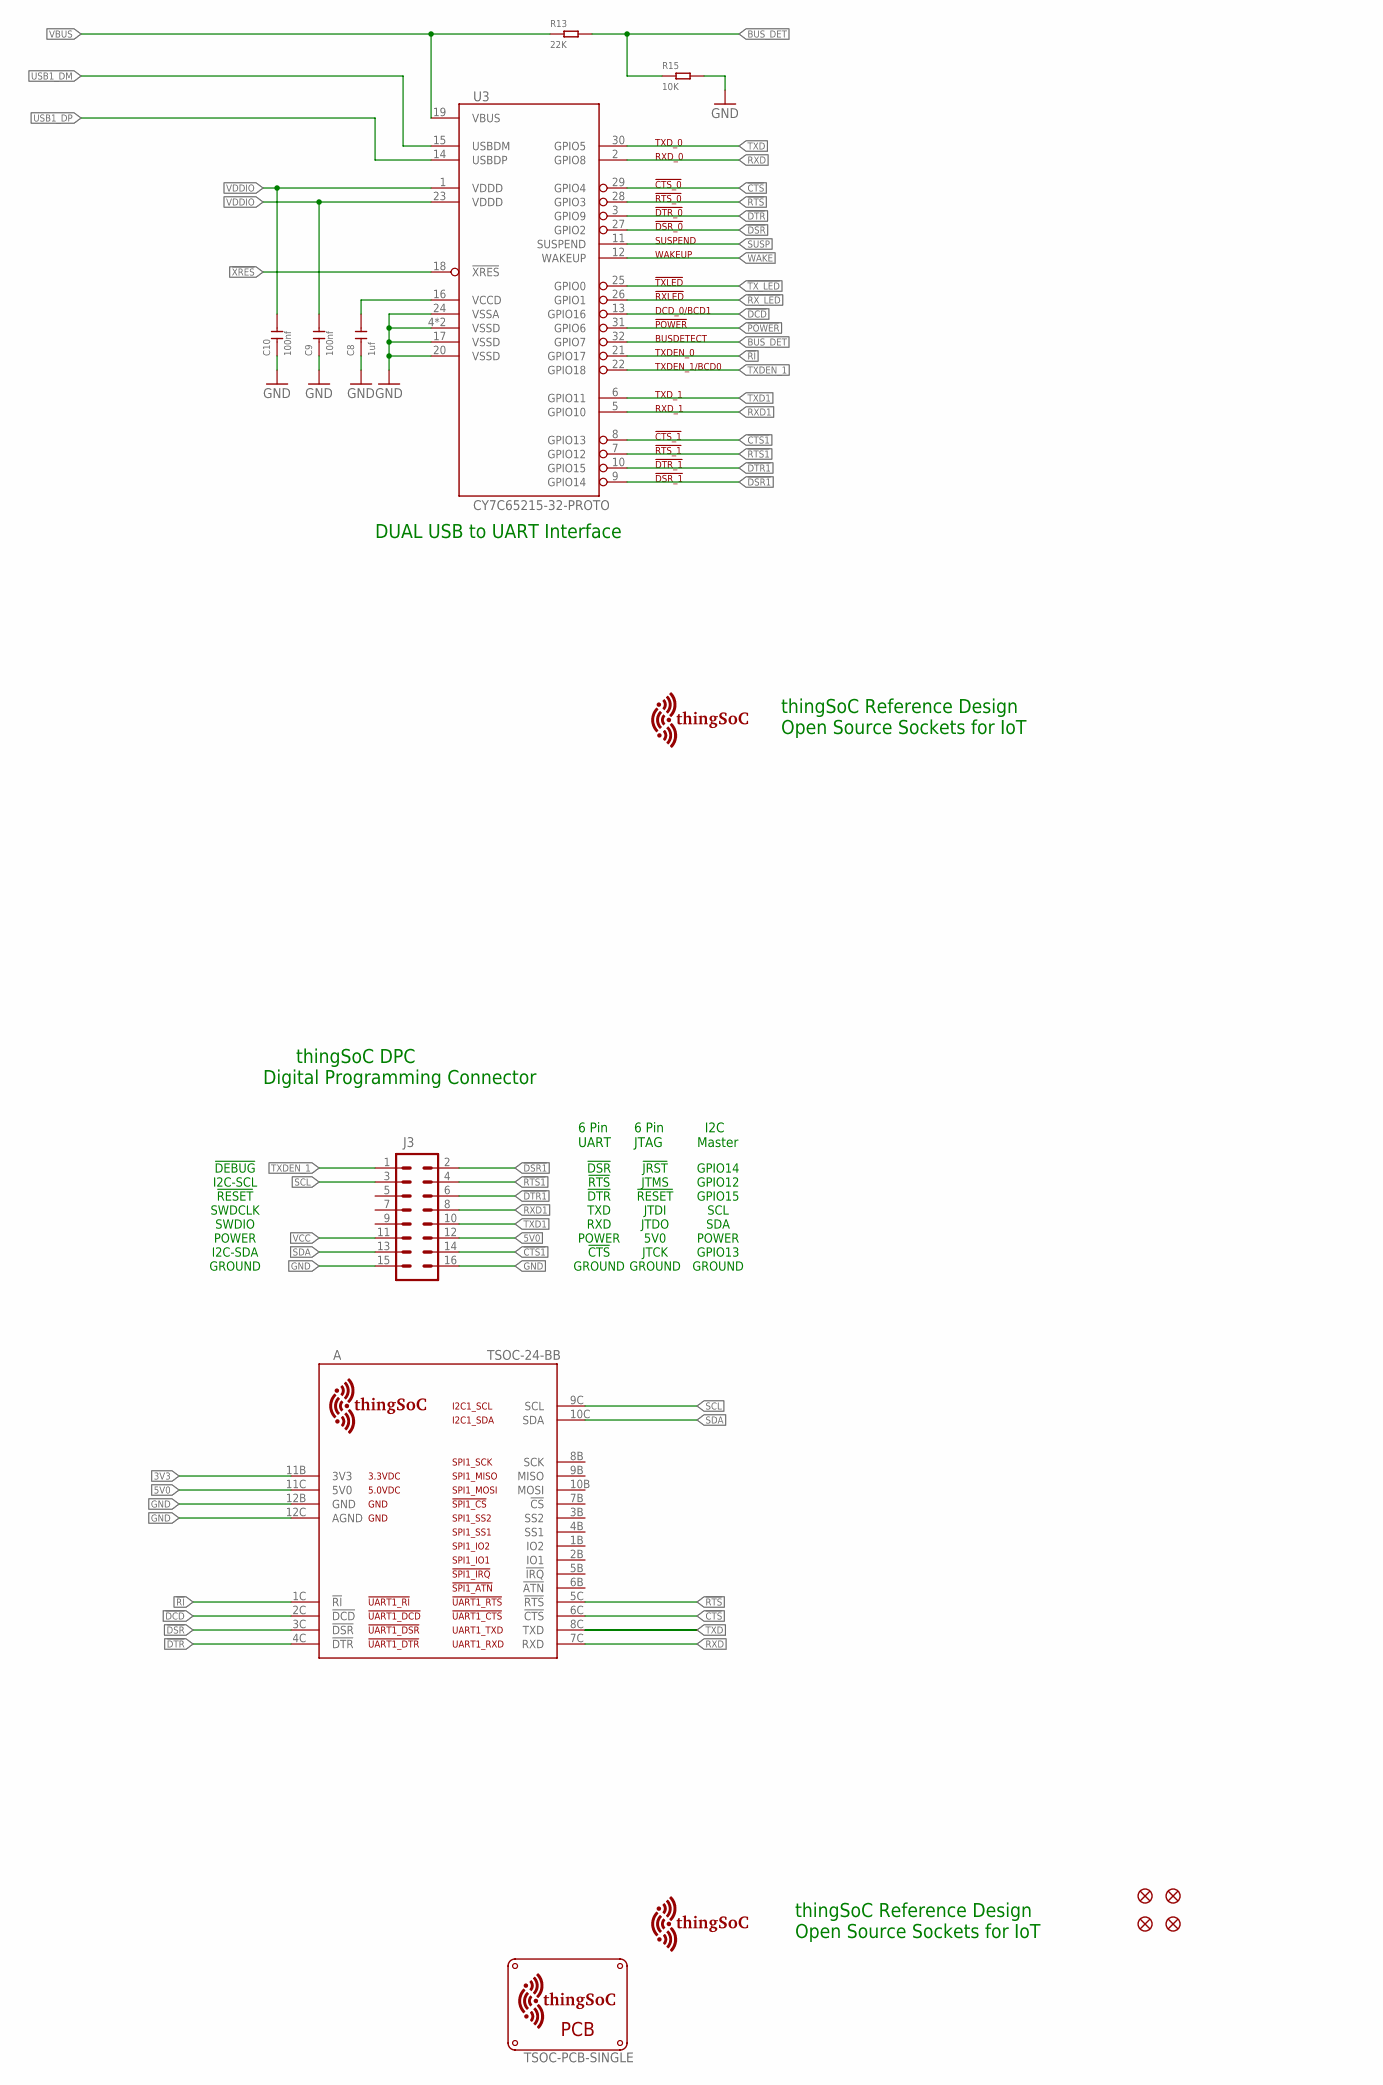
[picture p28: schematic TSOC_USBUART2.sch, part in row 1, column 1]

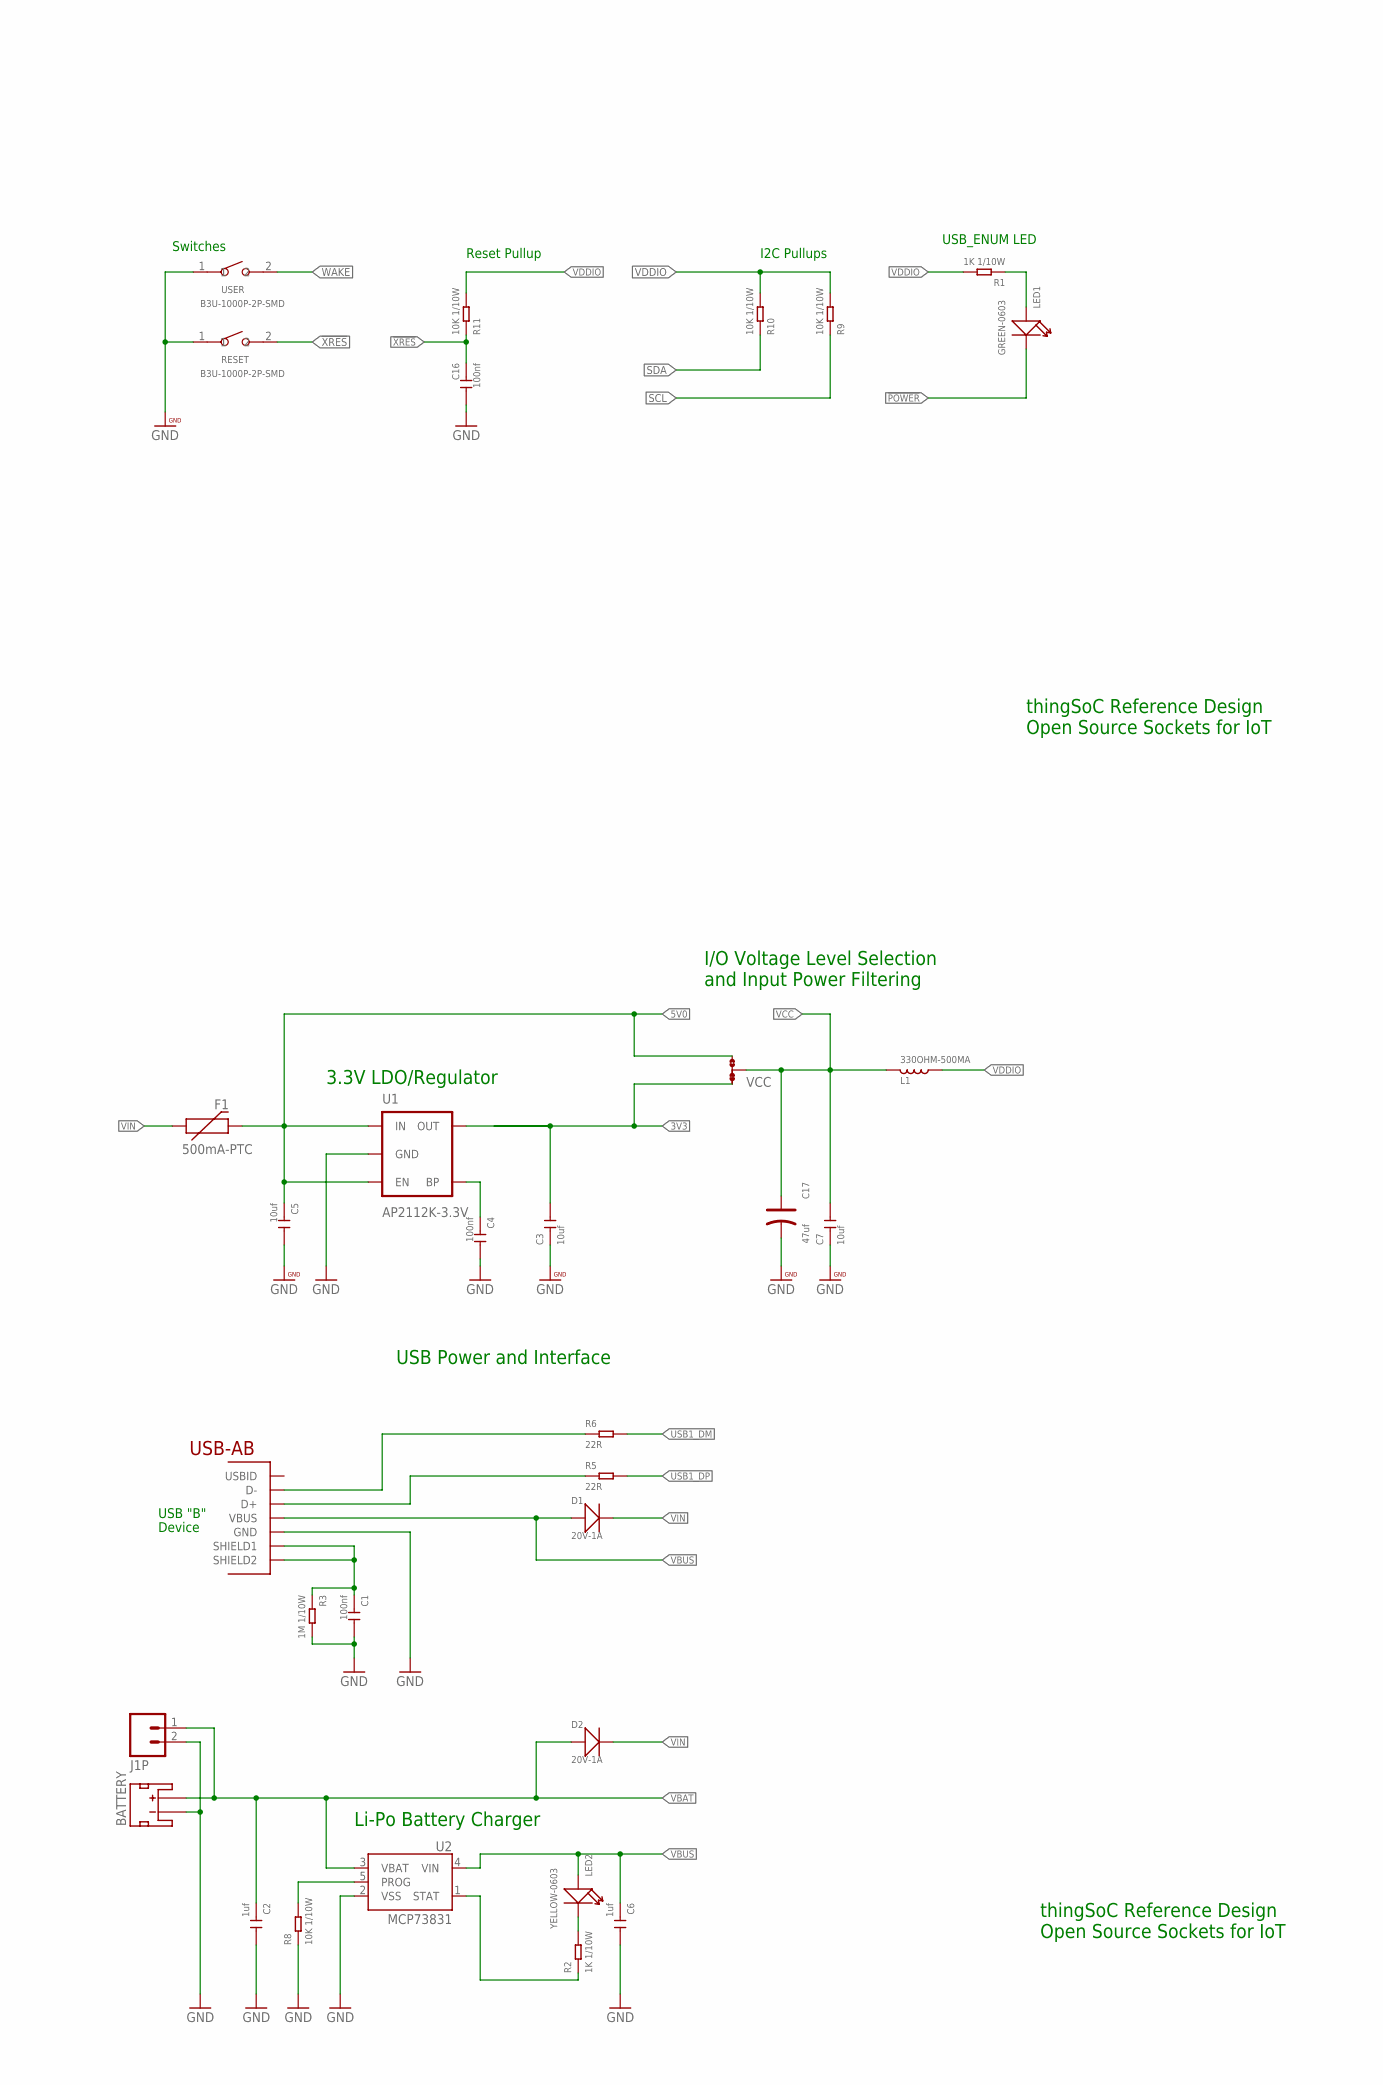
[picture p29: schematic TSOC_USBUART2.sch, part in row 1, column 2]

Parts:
A: TSOC-24-BB; TSOC-BB-S24
BATTERY: JST_2MM_MALE; JST-2-SMD
C1, C4, C9, C10, C16: 100nf; C0603
C2, C6, C8: 1uf; C0603
C3, C5, C7: 10uf; C0603
C17: 47uf; AVX-A
D1, D2: 20V-1A; SOD-123
F1: 500mA-PTC; PTC-1206
FID1, FID2, FID3, FID4: FIDUCIALUFIDUCIAL; MICRO-FIDUCIAL
J1P: M02-JST-2-PTH-NO_SILK; JST-2-PTH-NS
J3: M08X2; 2X8
L1: 330OHM-500MA; L0603
LED1: GREEN-0603; LED-0603
LED2: YELLOW-0603; LED-0603
R1, R2: 1K 1/10W; R0603
R3: 1M 1/10W; R0603
R5, R6: 22R; R0603
R8, R9, R10, R11: 10K 1/10W; R0603
R13: 22K; R0603
R15: 10K; R0603
RESET: B3U-1000P-2P-SMD; SW2-2.6-3.0X2.5X1.2+0.4MM
U1: AP2112K-3.3V; SOT23-5
U2: MCP73831; SOT23-5
U3: CY7C65215-32-PROTO; QFN32-PROTO
U$1: TSOC-PCB-SINGLE; TSOC-BB-BRD-DIM
U$100: TSOC-LOGO-LRG
U$101: TSOC-LOGO-SMALL; TSOC-LOGO-SML
USB: USB_AB; USB-AB-MICRO-SMD
USER: B3U-1000P-2P-SMD; SW2-2.6-3.0X2.5X1.2+0.4MM
VCC: JMP-3-1_2

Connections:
3V3: A.11B (3V3), C3.2, U1.5 (OUT), VCC.1
5V0: A.11C (5V0), C5.1, F1.2, J3.12, U1.1 (IN), U1.3 (EN), VCC.3
!CTS: A.6C (!CTS), U3.29 (GPIO4)
!CTS1: J3.14, U3.8 (GPIO13)
!DCD: A.2C (!DCD), U3.13 (GPIO16)
!DSR: A.3C (!DSR), U3.27 (GPIO2)
!DSR1: J3.2, U3.9 (GPIO14)
!DTR: A.4C (!DTR), U3.3 (GPIO9)
!DTR1: J3.6, U3.10 (GPIO15)
!POWER: LED1.-, U3.31 (GPIO6)
!RI: A.1C (!RI), U3.21 (GPIO17)
!RTS: A.5C (!RTS), U3.28 (GPIO3)
!RTS1: J3.4, U3.7 (GPIO12)
!RX_LED: U3.26 (GPIO1)
!TX_LED: U3.25 (GPIO0)
!XRES: C16.1, R11.1, RESET.2, U3.18 (!XRES)
BUS_DET: R13.2, R15.1, U3.32 (GPIO7)
BYPASS1: C4.1, U1.4 (BP)
CLED: LED2.-, R2.2
CSTAT: R2.1, U2.1 (STAT)
GND: A.12B (GND), A.12C (AGND), BATTERY.1 (-), C1.2, C2.2, C3.1, C4.2, C5.2, C6.2, C7.1, C8.1, C9.1, C10.1, C16.2, C17.-, J1P.2, J3.15, J3.16, R3.2, R8.1, R15.2, RESET.1, U1.2 (GND), U2.2 (VSS), U3.4 (VSSD), U3.17 (VSSD), U3.20 (VSSD), U3.24 (VSSA), U3.EXP (VSSD), USB.GND, USER.1
unnamed: R8.2, U2.5 (PROG)
unnamed: LED1.+, R1.1
RXD: A.7C (RXD), U3.2 (GPIO8)
RXD1: J3.8, U3.5 (GPIO10)
SCL: A.9C (SCL), J3.3, R9.1
SDA: A.10C (SDA), J3.13, R10.1
SUSP: U3.11 (SUSPEND)
TXD: A.8C (TXD), U3.30 (GPIO5)
TXD1: J3.10, U3.6 (GPIO11)
TXDEN_1: J3.1, U3.22 (GPIO18)
USB1_DM: R6.2, U3.15 (USBDM)
USB1_DP: R5.2, U3.14 (USBDP)
USB1_M: R6.1, USB.D-
USB1_P: R5.1, USB.D+
USB1_SHIELD: C1.1, R3.1, USB.SHIELD1, USB.SHIELD2
VBAT: BATTERY.2 (+), C2.1, D2.+, J1P.1, U2.3 (VBAT)
VBUS: C6.1, D1.+, LED2.+, R13.1, U2.4 (VIN), U3.19 (VBUS), USB.VBUS
VCC: C7.2, C17.+, J3.11, L1.1, VCC.2
VCCD: C8.2, U3.16 (VCCD)
VDDIO: C9.2, C10.2, L1.2, R1.2, R9.2, R10.2, R11.2, U3.1 (VDDD), U3.23 (VDDD)
VIN: D1.-, D2.-, F1.1
WAKE: U3.12 (WAKEUP), USER.2

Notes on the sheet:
USB "B"
Device
3.3V LDO/Regulator
Reset Pullup
USB_ENUM LED
Li-Po Battery Charger
USB Power and Interface
I/O Voltage Level Selection and Input Power Filtering
I2C Pullups
thingSoC Reference Design Open Source Sockets for IoT
thingSoC DPC Digital Programming Connector
Switches
DUAL USB to UART Interface
I2C-SDA
I2C-SCL
!RESET
SWDCLK
SWDIO
POWER
GROUND
!DEBUG
!DSR
!RTS
!CTS
!DTR
TXD
RXD
!JRST
JTMS
JTCK
JTDI
JTDO
5V0
6 Pin UART
6 Pin JTAG
I2C Master
GPIO14
GPIO12
GPIO13
GPIO15

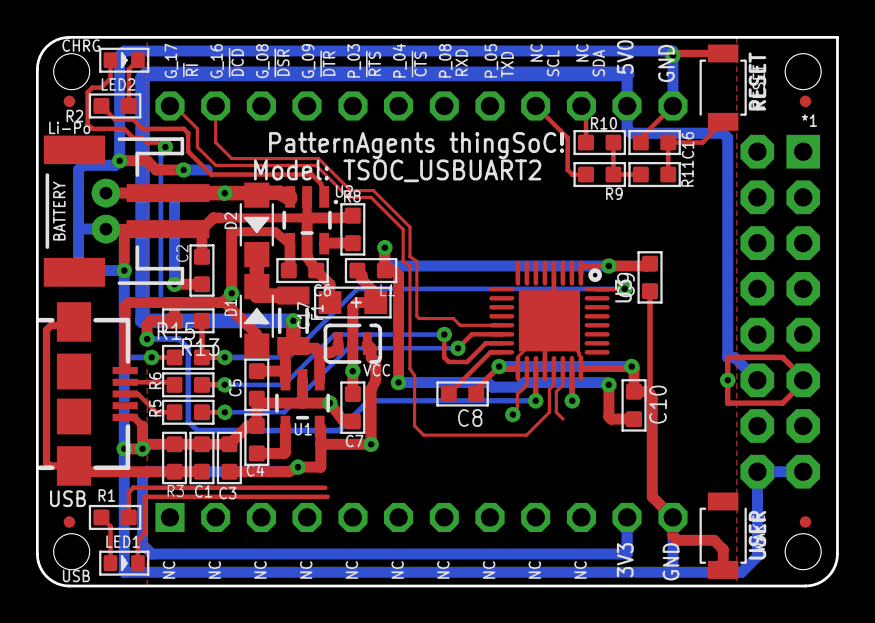
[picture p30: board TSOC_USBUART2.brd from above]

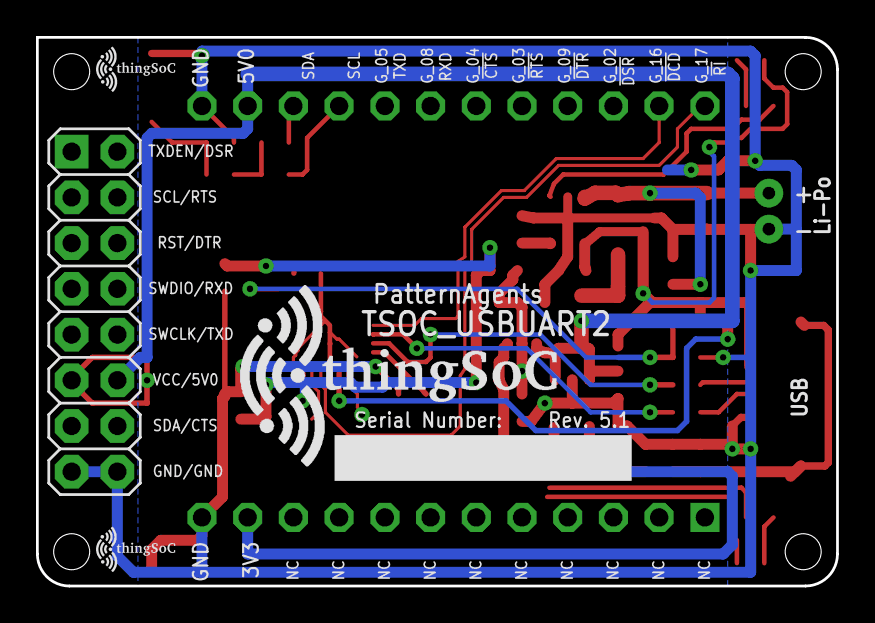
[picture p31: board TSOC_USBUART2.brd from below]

Board: 2 copper layers, 44.5 x 30.5 mm, 48 parts (5 on the bottom side), 40 nets.

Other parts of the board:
U$102: TSOC-LOGO-SMALL; TSOC-LOGO-SML

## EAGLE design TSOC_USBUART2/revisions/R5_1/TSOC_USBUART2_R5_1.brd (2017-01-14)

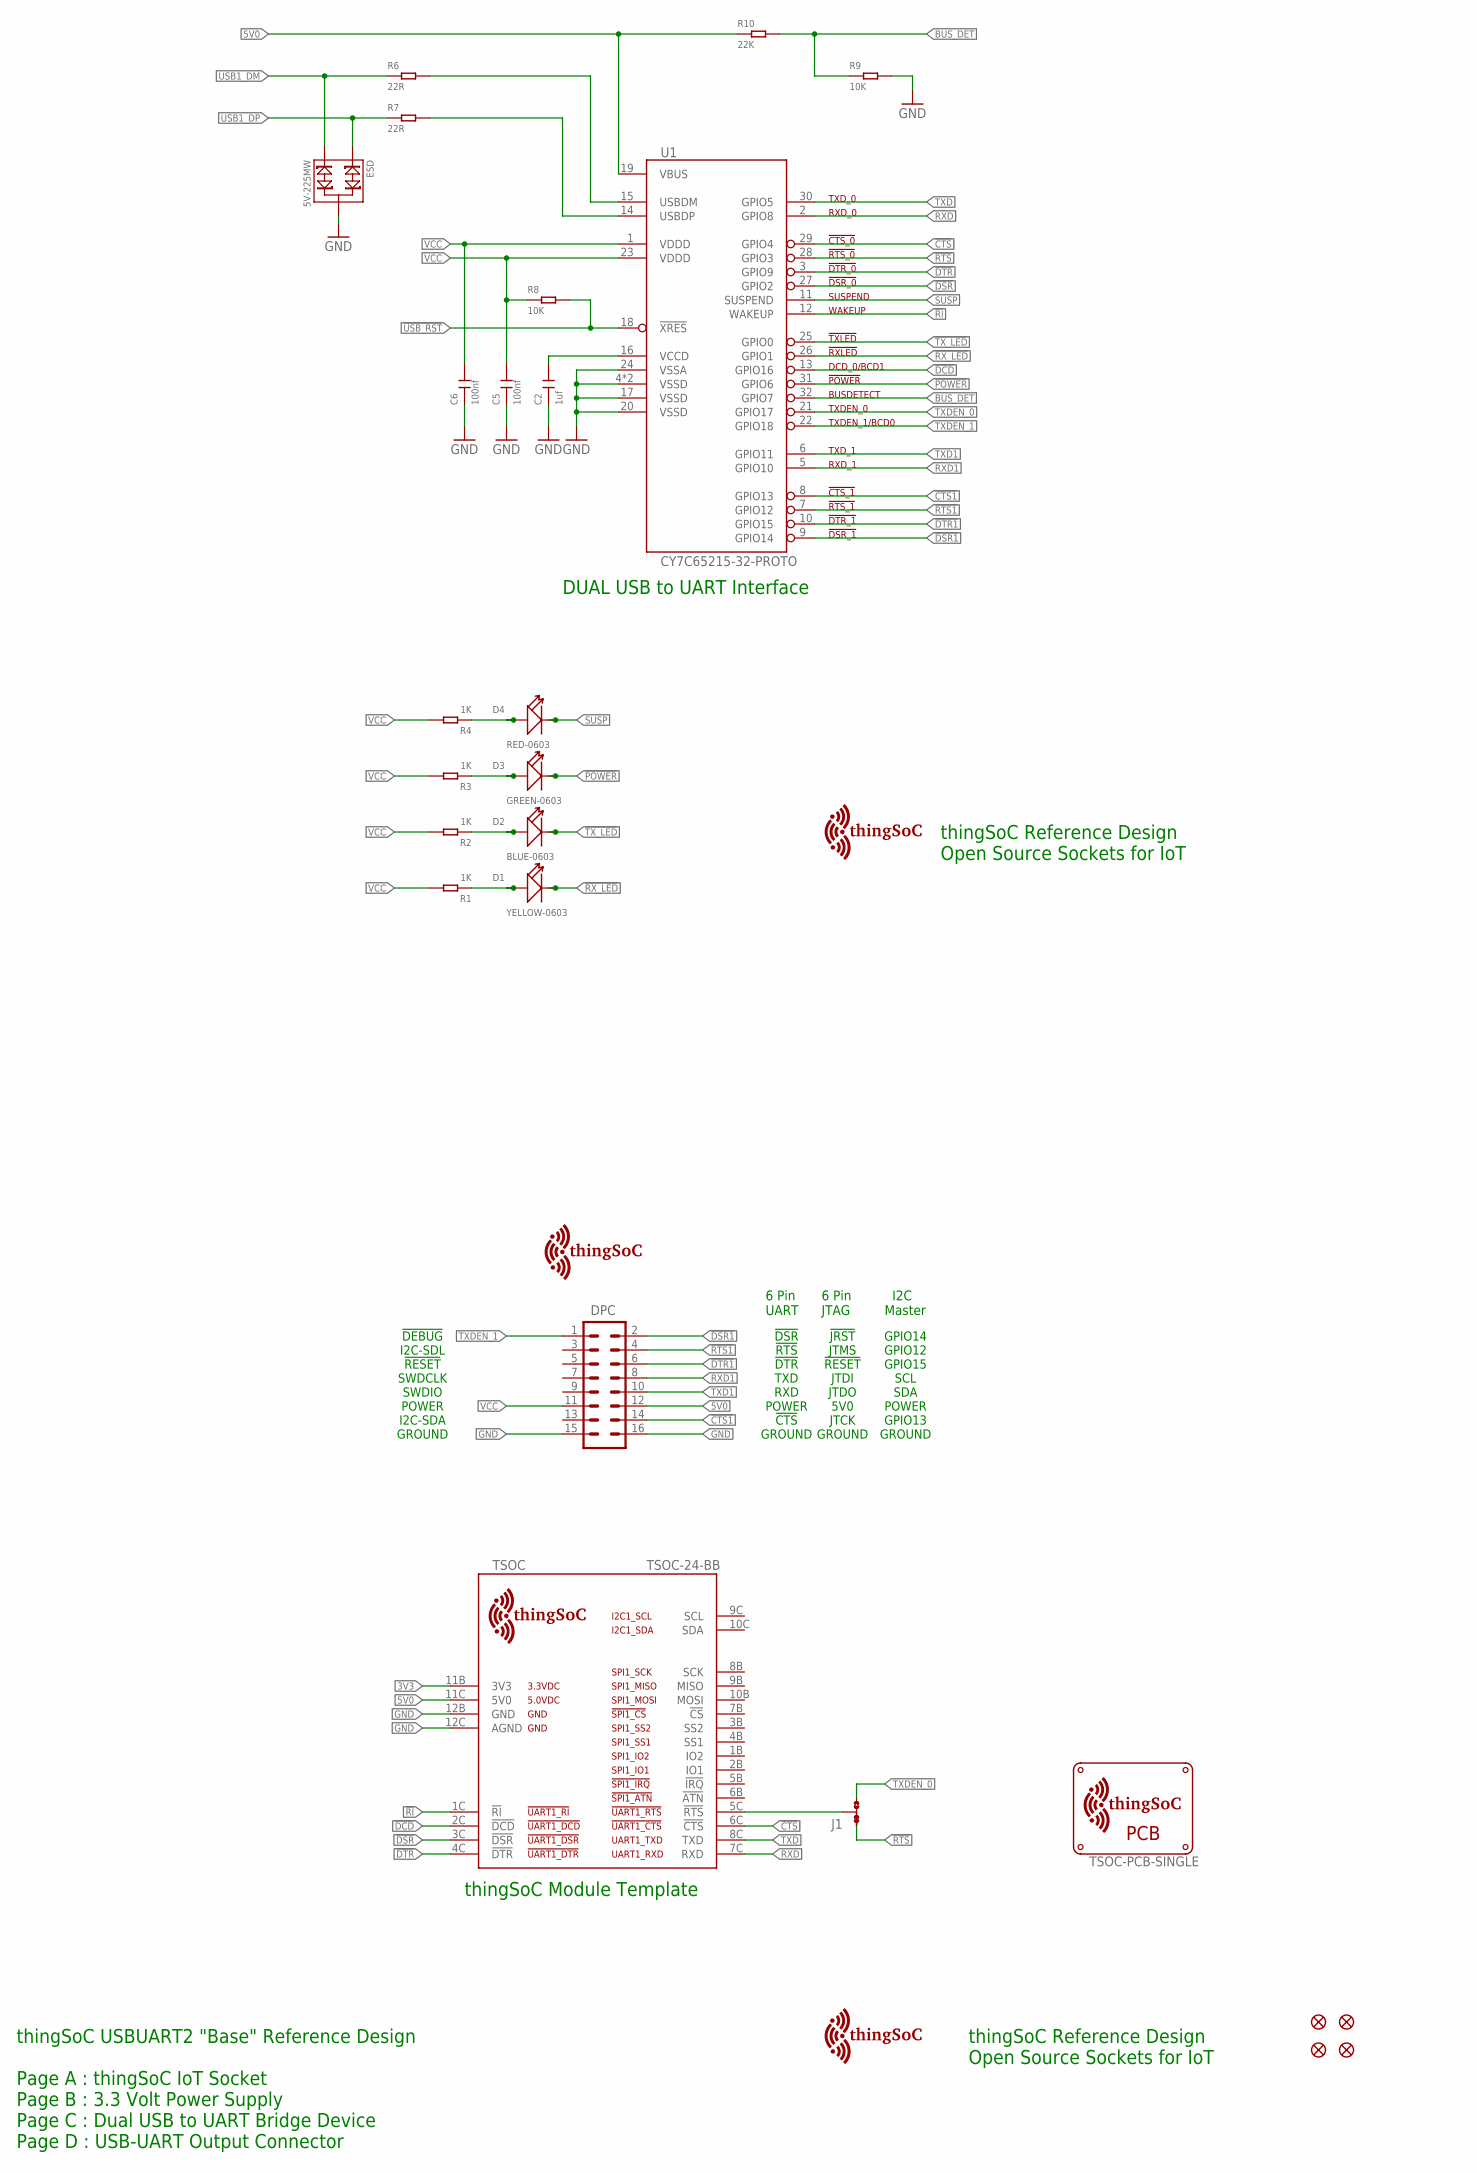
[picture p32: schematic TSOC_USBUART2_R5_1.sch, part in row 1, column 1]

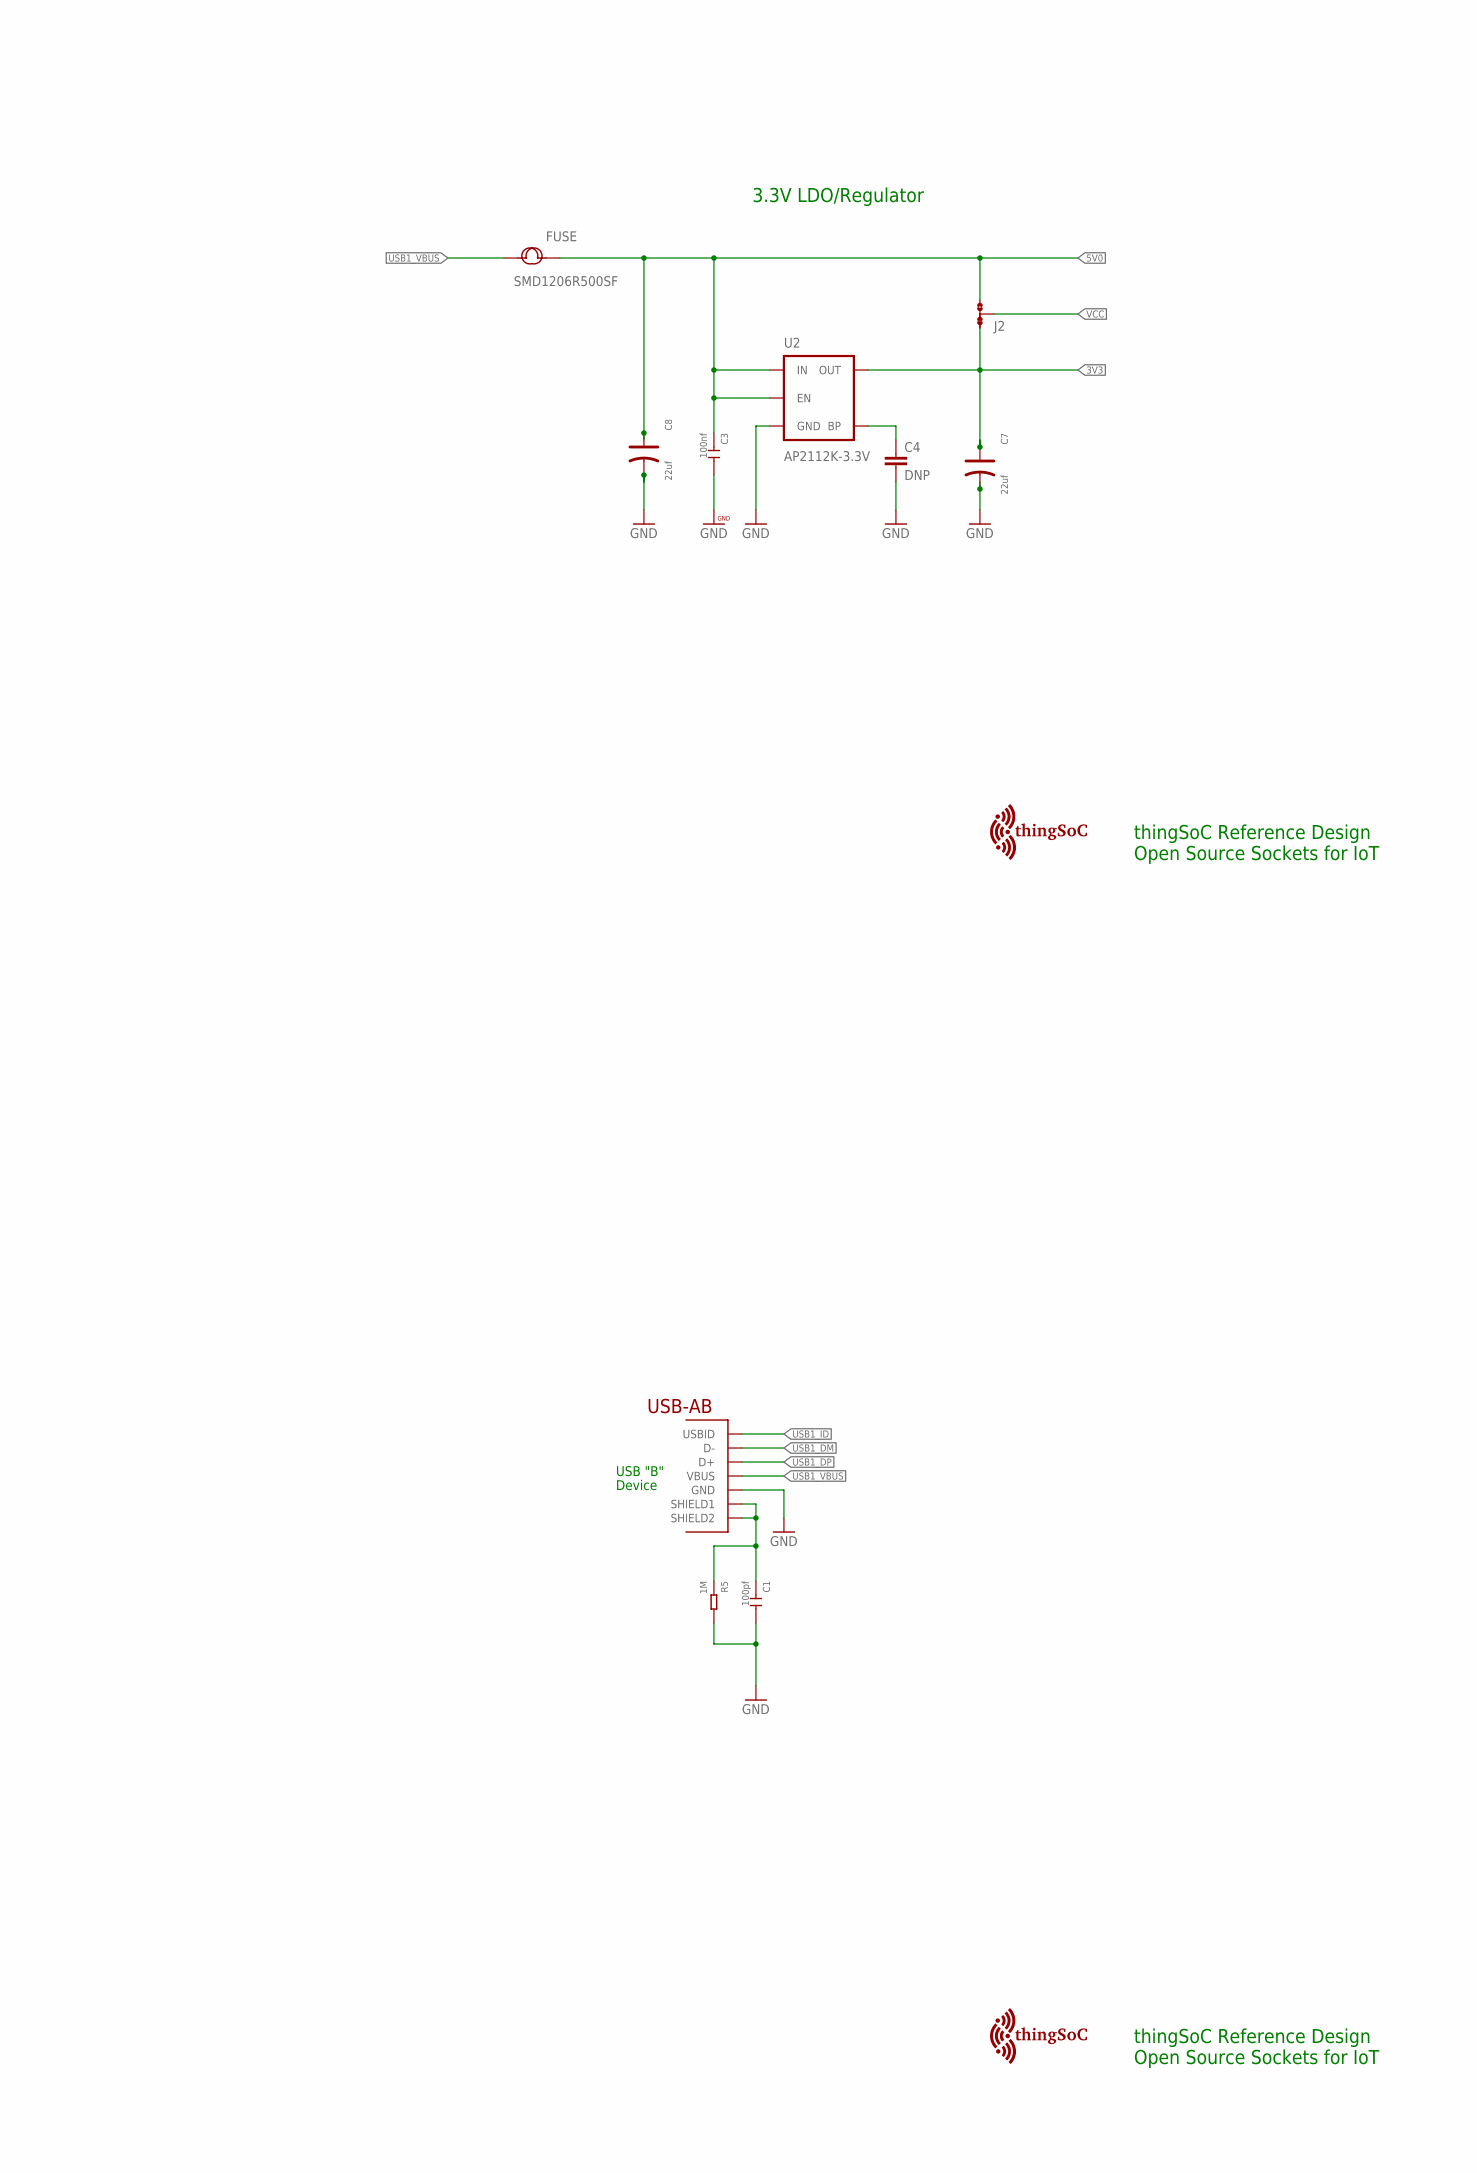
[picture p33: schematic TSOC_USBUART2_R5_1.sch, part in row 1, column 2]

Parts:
$$U$2: TSOC-LOGO; TSOC-LOGO-BLANK
C1: 100pf; C0603
C2: 1uf; C0603
C3, C5, C6: 100nf; C0603
C4: DNP; EIA-0603
C7, C8: 22uf; AVX-A
D1: YELLOW-0603; LED-0603
D2: BLUE-0603; LED-0603
D3: GREEN-0603; LED-0603
D4: RED-0603; LED-0603
DPC: M08X2; 2X8
ESD: 5V-225MW; SOT-23
FID1, FID2, FID3, FID4: FIDUCIALUFIDUCIAL; MICRO-FIDUCIAL
FUSE: SMD1206R500SF; F1206
J1, J2: JMP-3-1_2
R1, R2, R3, R4: 1K; R0603
R5: 1M; R0603
R6, R7: 22R; R0603
R8, R9: 10K; R0603
R10: 22K; R0603
TSOC: TSOC-24-BB; TSOC-BB-S24
U1: CY7C65215-32-PROTO; QFN32-PROTO
U2: AP2112K-3.3V; SOT23-5
U$1, U$3: TSOC-LOGO; TSOC-LOGO-BLANK
U$4: TSOC-PCB-SINGLE; TSOC-BB-BRD-DIM
U$7: TSOC-LOGO-SMALL; TSOC-LOGO-SML
U$100: TSOC-LOGO-LRG
USB: USB_AB; USB-AB-MICRO-SMD

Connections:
3V3: C7.+, J2.1, TSOC.11B (3V3), U2.5 (OUT)
5V0: C3.1, C8.+, DPC.12, FUSE.2, J2.3, R10.1, TSOC.11C (5V0), U1.19 (VBUS), U2.1 (IN), U2.3 (EN)
!CTS: TSOC.6C (!CTS), U1.29 (GPIO4)
!CTS1: DPC.14, U1.8 (GPIO13)
!DCD: TSOC.2C (!DCD), U1.13 (GPIO16)
!DSR: TSOC.3C (!DSR), U1.27 (GPIO2)
!DSR1: DPC.2, U1.9 (GPIO14)
!DTR: TSOC.4C (!DTR), U1.3 (GPIO9)
!DTR1: DPC.6, U1.10 (GPIO15)
!POWER: D3.-, U1.31 (GPIO6)
!RI: TSOC.1C (!RI), U1.12 (WAKEUP)
!RTS: J1.1, U1.28 (GPIO3)
!RTS1: DPC.4, U1.7 (GPIO12)
!RX_LED: D1.-, U1.26 (GPIO1)
!TX_LED: D2.-, U1.25 (GPIO0)
!USB_RST: R8.2, U1.18 (!XRES)
BLU: D2.+, R2.1
BUS_DET: R9.1, R10.2, U1.32 (GPIO7)
BYPASS1: C4.1, U2.4 (BP)
GND: C1.2, C2.1, C3.2, C4.2, C5.1, C6.1, C7.-, C8.-, DPC.15, DPC.16, ESD.3, R5.2, R9.2, TSOC.12B (GND), TSOC.12C (AGND), U1.4 (VSSD), U1.17 (VSSD), U1.20 (VSSD), U1.24 (VSSA), U1.EXP (VSSD), U2.2 (GND), USB.GND
GRN: D3.+, R3.1
unnamed: J1.2, TSOC.5C (!RTS)
RED: D4.+, R4.1
RXD: TSOC.7C (RXD), U1.2 (GPIO8)
RXD1: DPC.8, U1.5 (GPIO10)
SUSP: D4.-, U1.11 (SUSPEND)
TXD: TSOC.8C (TXD), U1.30 (GPIO5)
TXD1: DPC.10, U1.6 (GPIO11)
TXDEN_0: J1.3, U1.21 (GPIO17)
TXDEN_1: DPC.1, U1.22 (GPIO18)
USB1_DM: ESD.2, R6.1, USB.D-
USB1_DP: ESD.1, R7.1, USB.D+
USB1_ID: USB.ID (USBID)
USB1_M: R6.2, U1.15 (USBDM)
USB1_P: R7.2, U1.14 (USBDP)
USB1_SHIELD: C1.1, R5.1, USB.SHIELD1, USB.SHIELD2
USB1_VBUS: FUSE.1, USB.VBUS
VCC: C5.2, C6.2, DPC.11, J2.2, R1.2, R2.2, R3.2, R4.2, R8.1, U1.1 (VDDD), U1.23 (VDDD)
VCCD1: C2.2, U1.16 (VCCD)
YEL: D1.+, R1.1

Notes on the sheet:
thingSoC Reference Design Open Source Sockets for IoT
USB "B"
Device
thingSoC USBUART2 "Base" Reference Design Page A : thingSoC IoT Socket Page B : 3.3 Volt Power Supply Page C : Dual USB to UART Bridge Device Page D : USB-UART Output Connector
DUAL USB to UART Interface
thingSoC Module Template
3.3V LDO/Regulator
I2C-SDA
I2C-SDL
!RESET
SWDCLK
SWDIO
POWER
GROUND
!DEBUG
!DSR
!RTS
!CTS
!DTR
TXD
RXD
!JRST
JTMS
JTCK
JTDI
JTDO
5V0
6 Pin UART
6 Pin JTAG
I2C Master
GPIO14
GPIO12
GPIO13
GPIO15
SCL
SDA

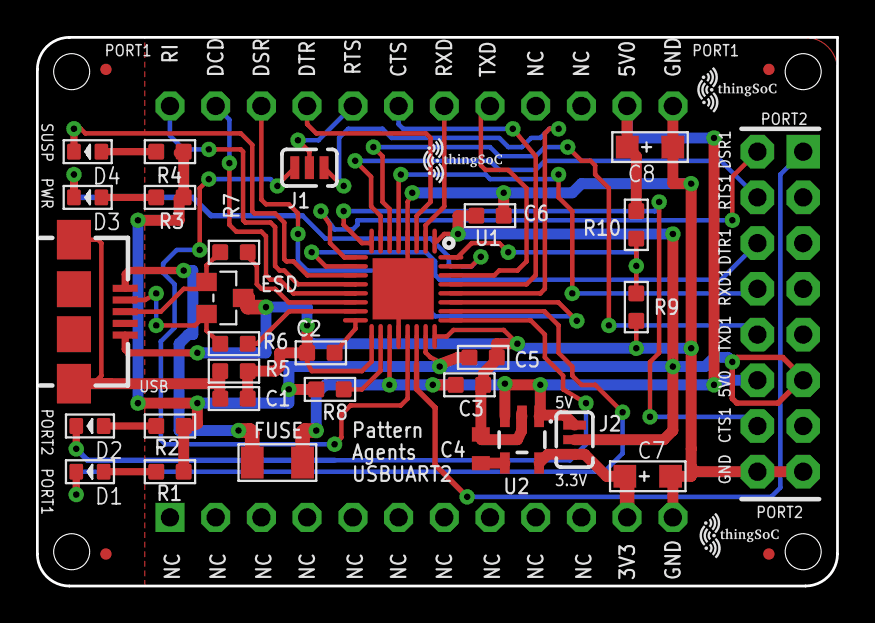
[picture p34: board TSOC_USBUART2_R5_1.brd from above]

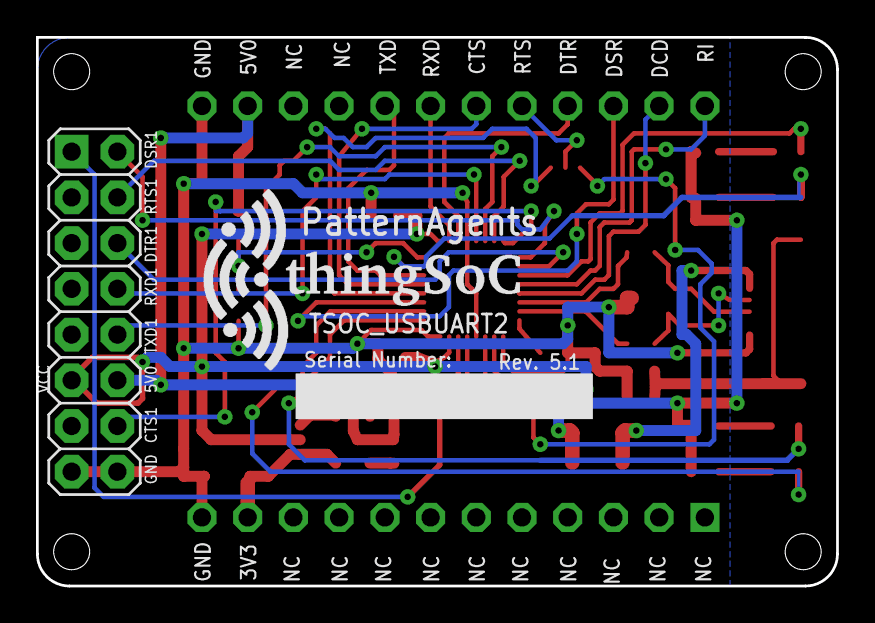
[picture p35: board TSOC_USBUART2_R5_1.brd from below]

Board: 2 copper layers, 44.5 x 30.5 mm, 43 parts (2 on the bottom side), 39 nets.

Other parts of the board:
U$5, U$6: TSOC-LOGO-SMALL; TSOC-LOGO-SML

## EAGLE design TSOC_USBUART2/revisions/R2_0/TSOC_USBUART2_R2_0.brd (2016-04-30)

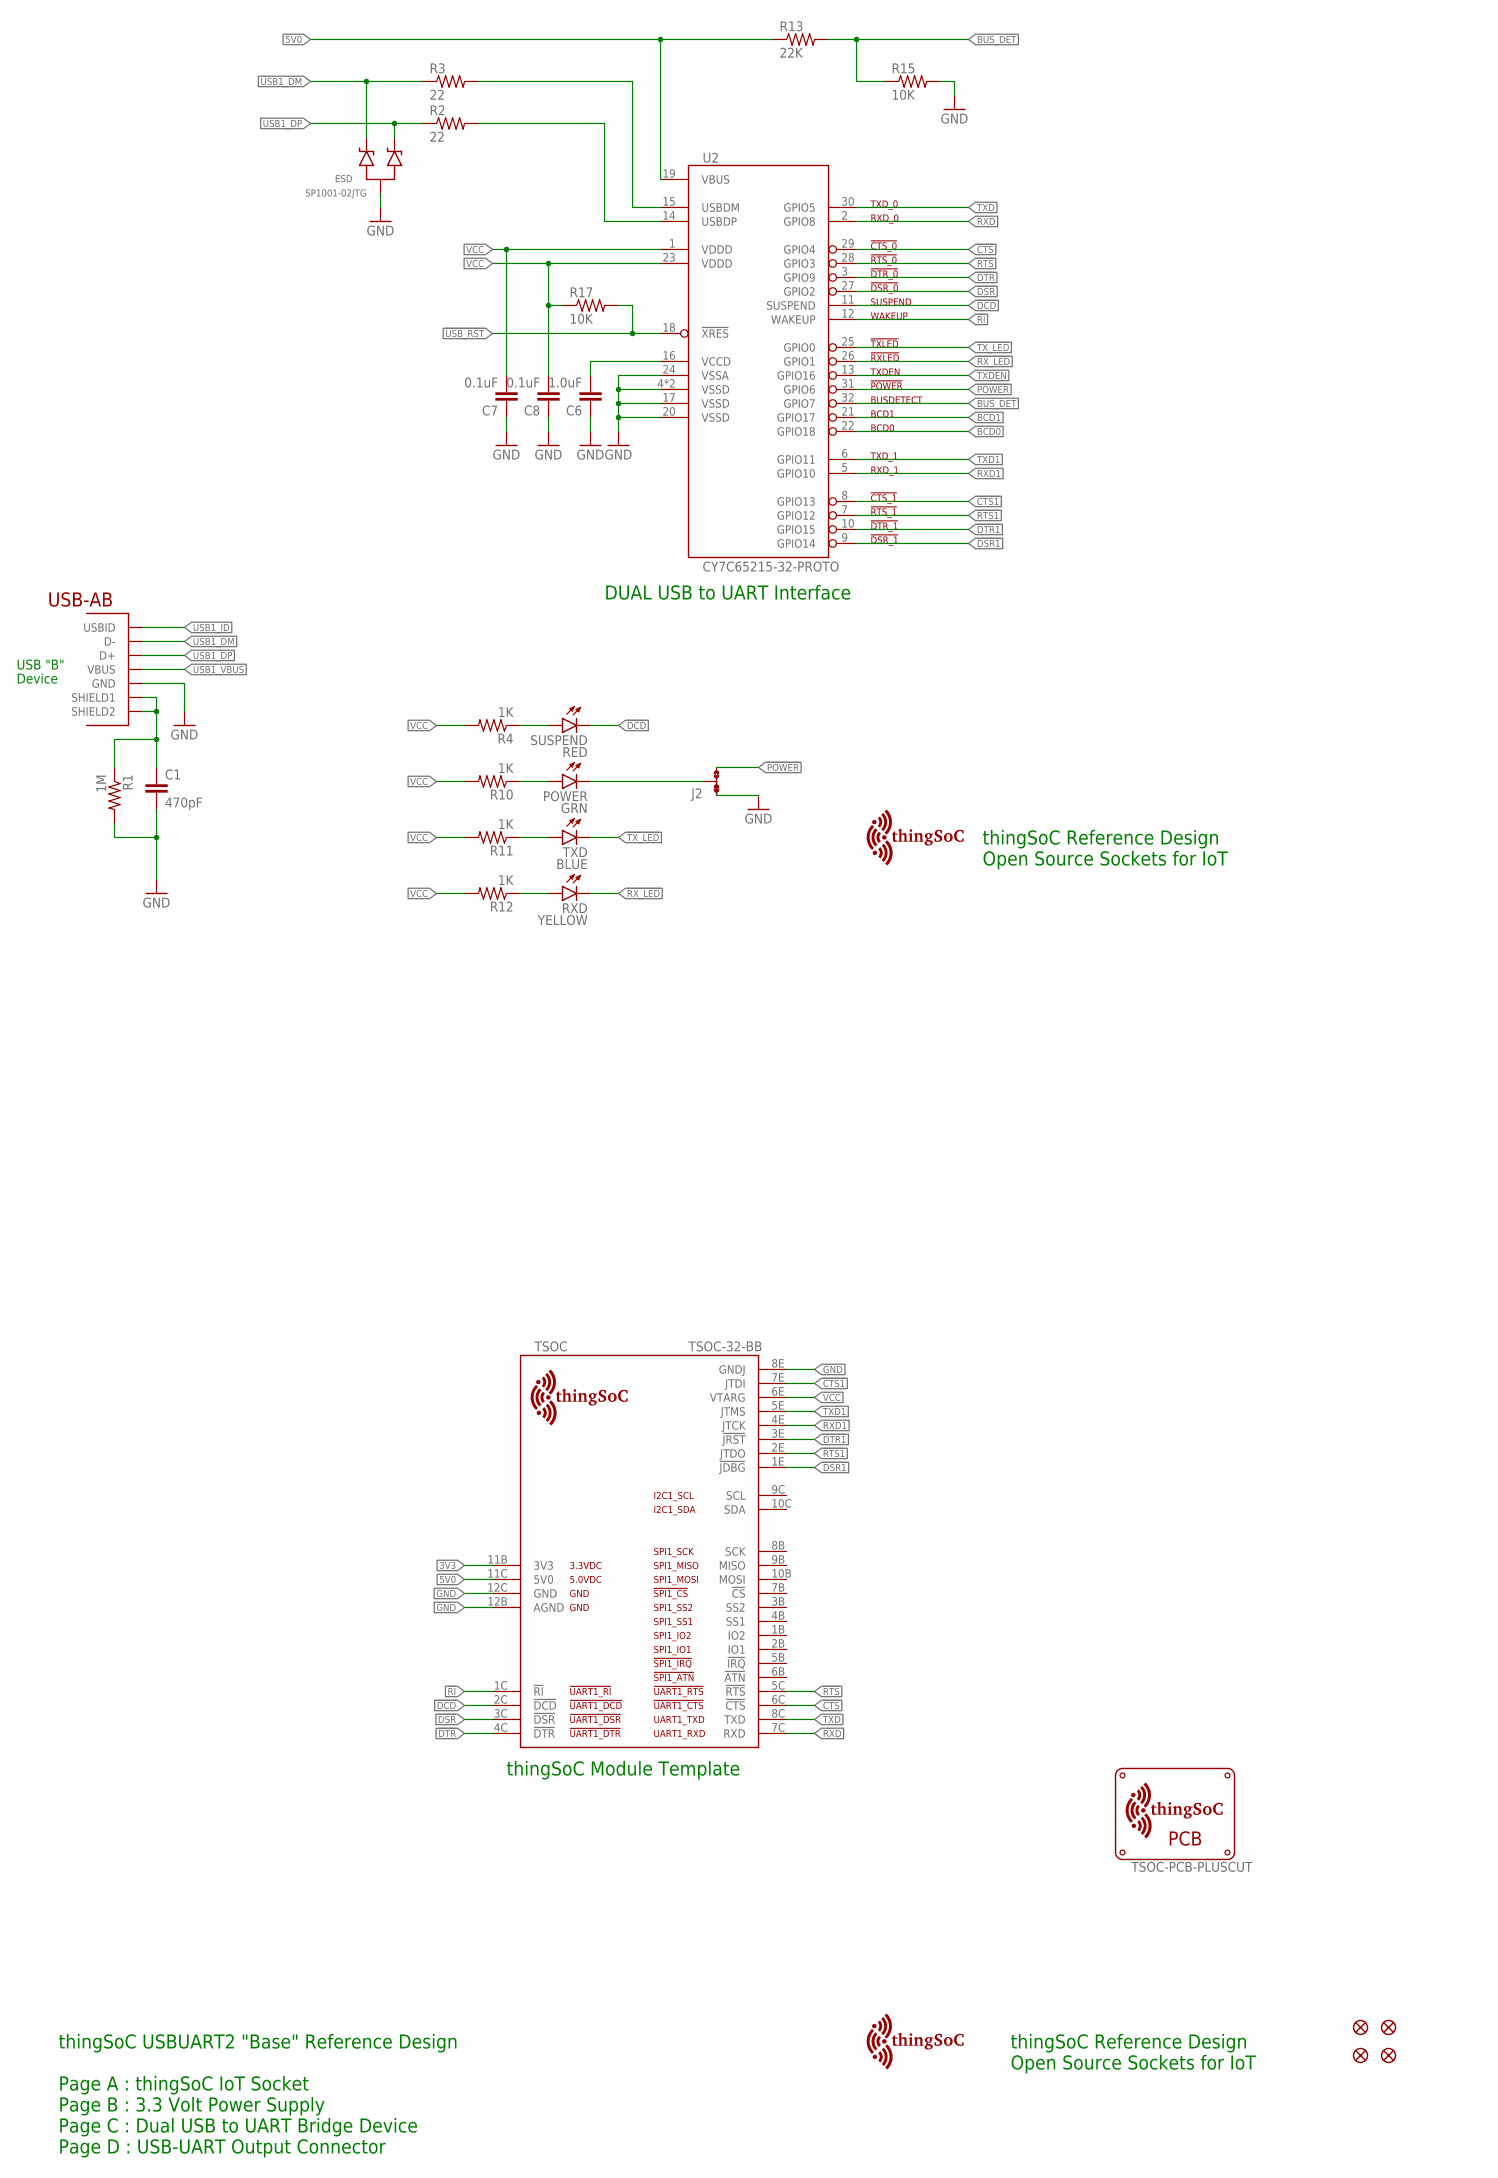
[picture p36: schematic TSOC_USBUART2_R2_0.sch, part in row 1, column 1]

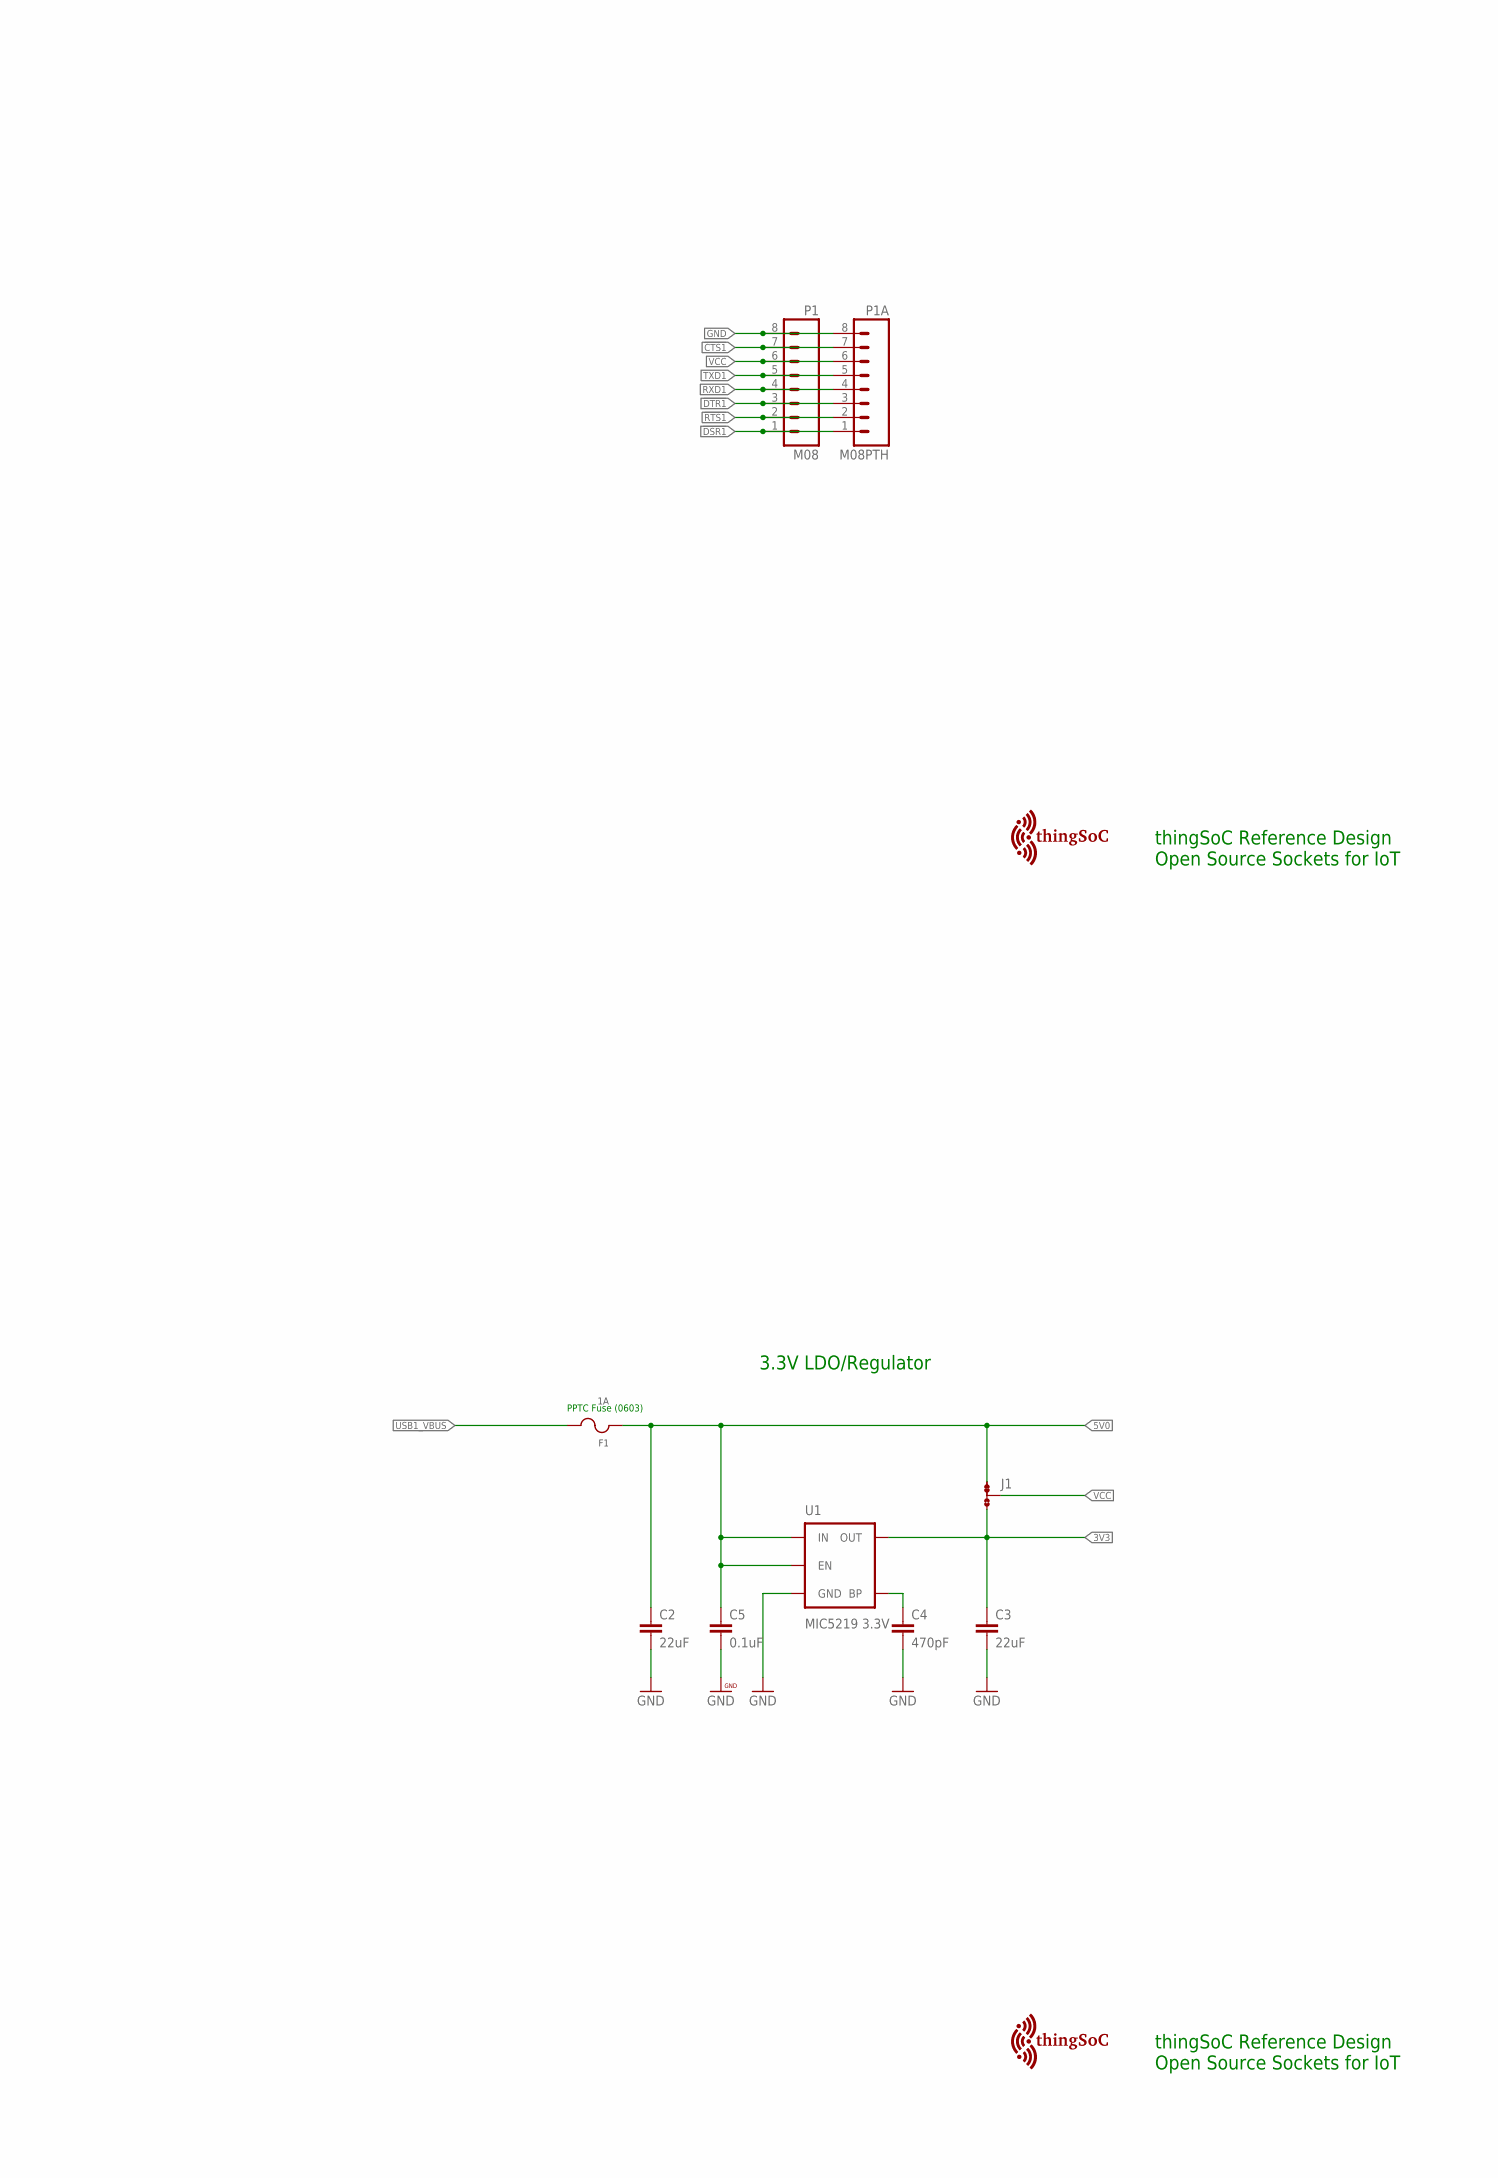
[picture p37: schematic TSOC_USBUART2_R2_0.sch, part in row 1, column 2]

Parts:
C1, C4: 470pF; EIA-0603
C2, C3: 22uF; EIA-1206
C5, C7, C8: 0.1uF; EIA-0603
C6: 1.0uF; EIA-0603
ESD: SP1001-02JTG; SC70-3
F1: 1A; EIA-0603
FID1, FID2, FID3, FID4: FIDUCIALUFIDUCIAL; MICRO-FIDUCIAL
J1, J2: JMP-3-1_2
P1: M08; 1X08-SMD-FEMALE
P1A: M08PTH; 1X08
POWER: GRN; LED-0603
R1: 1M; EIA-0603
R2, R3: 22; EIA-0603
R4, R10, R11, R12: 1K; EIA-0603
R13: 22K; EIA-0603
R15, R17: 10K; EIA-0603
RXD: YELLOW; LED-0603
SUSPEND: RED; LED-0603
TSOC: TSOC-32-BB; TSOC-BB-S32
TXD: BLUE; LED-0603
U1: MIC5219 3.3V; SOT23-5
U2: CY7C65215-32-PROTO; QFN32-PROTO
U$3: TSOC-LOGO-LRG
U$4, U$5, U$6: TSOC-LOGO; TSOC-LOGO-BLANK
U$7: TSOC-PCB-PLUSCUT; TSOC-BB-BRD-PLUS-CUT
USB: USB_AB; USB-AB-MICRO-SMD

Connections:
3V3: C3.1, J1.3, TSOC.11B (3V3), U1.5 (OUT)
5V0: C2.1, C5.1, F1.1, J1.1, R13.1, TSOC.11C (5V0), U1.1 (IN), U1.3 (EN), U2.19 (VBUS)
!CTS: TSOC.6C (!CTS), U2.29 (GPIO4)
!CTS1: P1.7, P1A.7, TSOC.7E (JTDI), U2.8 (GPIO13)
!DCD: SUSPEND.C, TSOC.2C (!DCD), U2.11 (SUSPEND)
!DSR: TSOC.3C (!DSR), U2.27 (GPIO2)
!DSR1: P1.1, P1A.1, TSOC.1E (!JDBG), U2.9 (GPIO14)
!DTR: TSOC.4C (!DTR), U2.3 (GPIO9)
!DTR1: P1.3, P1A.3, TSOC.3E (!JRST), U2.10 (GPIO15)
!POWER: J2.3, U2.31 (GPIO6)
!RI: TSOC.1C (!RI), U2.12 (WAKEUP)
!RTS: TSOC.5C (!RTS), U2.28 (GPIO3)
!RTS1: P1.2, P1A.2, TSOC.2E (JTDO), U2.7 (GPIO12)
!RX_LED: RXD.C, U2.26 (GPIO1)
!TX_LED: TXD.C, U2.25 (GPIO0)
!USB_RST: R17.2, U2.18 (!XRES)
BCD0: U2.22 (GPIO18)
BCD1: U2.21 (GPIO17)
BLU: R11.1, TXD.A
BUS_DET: R13.2, R15.1, U2.32 (GPIO7)
BYPASS1: C4.1, U1.4 (BP)
GND: C1.2, C2.2, C3.2, C4.2, C5.2, C6.1, C7.1, C8.1, ESD.3 (A), J2.1, P1.8, P1A.8, R1.2, R15.2, TSOC.8E (GNDJ), TSOC.12B (AGND), TSOC.12C (GND), U1.2 (GND), U2.4 (VSSD), U2.17 (VSSD), U2.20 (VSSD), U2.24 (VSSA), U2.EXP (VSSD), USB.GND
GRN: POWER.A, R10.1
PWR: J2.2, POWER.C
RED: R4.1, SUSPEND.A
RXD: TSOC.7C (RXD), U2.2 (GPIO8)
RXD1: P1.4, P1A.4, TSOC.4E (JTCK), U2.5 (GPIO10)
TXD: TSOC.8C (TXD), U2.30 (GPIO5)
TXD1: P1.5, P1A.5, TSOC.5E (JTMS), U2.6 (GPIO11)
TXDEN: U2.13 (GPIO16)
USB1_DM: ESD.2 (C2), R3.1, USB.D-
USB1_DP: ESD.1 (C1), R2.1, USB.D+
USB1_ID: USB.ID (USBID)
USB1_M: R3.2, U2.15 (USBDM)
USB1_P: R2.2, U2.14 (USBDP)
USB1_SHIELD: C1.1, R1.1, USB.SHIELD1, USB.SHIELD2
USB1_VBUS: F1.2, USB.VBUS
VCC: C7.2, C8.2, J1.2, P1.6, P1A.6, R4.2, R10.2, R11.2, R12.2, R17.1, TSOC.6E (VTARG), U2.1 (VDDD), U2.23 (VDDD)
VCCD1: C6.2, U2.16 (VCCD)
YEL: R12.1, RXD.A

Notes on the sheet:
thingSoC Reference Design Open Source Sockets for IoT
USB "B"
Device
thingSoC USBUART2 "Base" Reference Design Page A : thingSoC IoT Socket Page B : 3.3 Volt Power Supply Page C : Dual USB to UART Bridge Device Page D : USB-UART Output Connector
DUAL USB to UART Interface
thingSoC Module Template
3.3V LDO/Regulator
PPTC Fuse (0603)

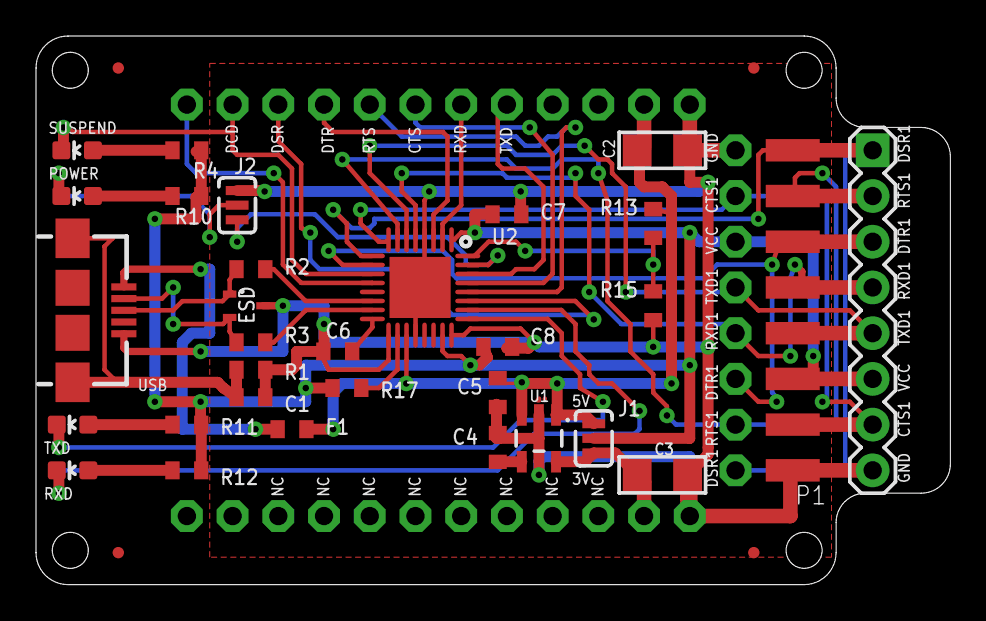
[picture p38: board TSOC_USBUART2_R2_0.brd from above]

Board: 2 copper layers, 50.8 x 30.5 mm, 41 parts (1 on the bottom side), 36 nets.

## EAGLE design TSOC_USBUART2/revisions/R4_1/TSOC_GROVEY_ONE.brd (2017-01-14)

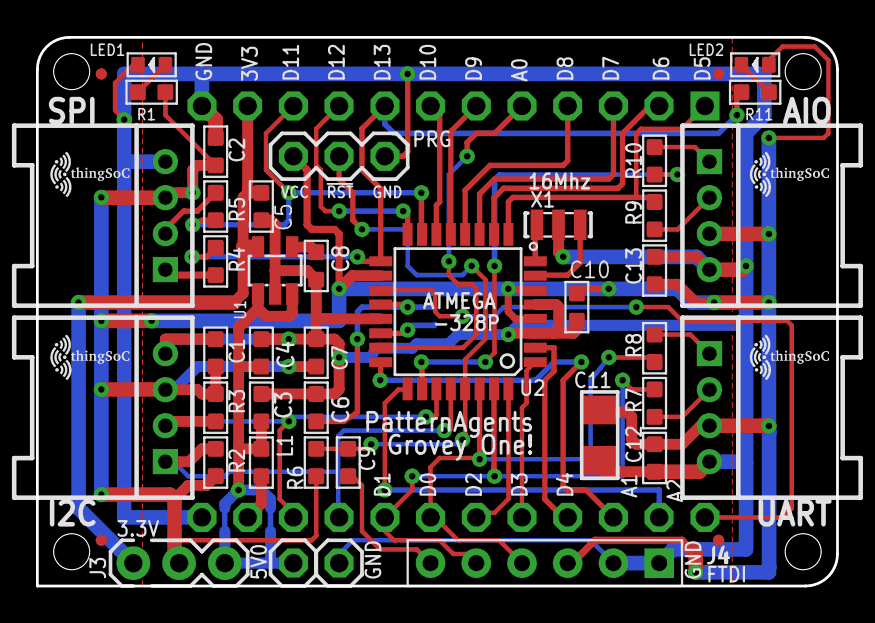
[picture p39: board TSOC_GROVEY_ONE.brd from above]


Board: 2 copper layers, 44.5 x 30.5 mm, 54 parts (5 on the bottom side), 41 nets.

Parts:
5V0: 1X01
$$U$1: TSOC-PCB-SINGLE; TSOC-BB-BRD-DIM
$$U$2, $$U$3: TSOC-LOGO-SMALL; TSOC-LOGO-SML
A7: JMP-2-NO
AIO: 4P-2.0-90D; HW4-2.0-90D
C1, C2, C4, C6, C7, C9, C10, C12, C13: 100nf; C0603
C3, C5: 10uf; C0603
C8: 470Pf; C0603
C11: 22uF; EIA-1206
FID1, FID2, FID3, FID4: FIDUCIALUFIDUCIAL; MICRO-FIDUCIAL
GND: 1X01
I2C: 4P-2.0-90D; HW4-2.0-90D
J3: NO; JMP-3-NO-PTH-2.54
J4: 6p-2.54; H6-2.54
L1: 120OHM-500MA; L0603
LED1: GREEN-0603; LED-0603
LED2: RED-0603; LED-0603
PRG: 1X03
R1, R4, R5, R7, R8, R9, R10, R11: 1K 1/10W; R0603
R2, R3: 2.2K; R0603
R6: 10K 1/10W; R0603
SPI: 4P-2.0-90D; HW4-2.0-90D
TSOC: TSOC-24-BB; TSOC-BB-S24
U1: XC6204B332MR-SOT23-5; SOT-23-5
U2: ATMEGA328; TQFP32-08
U$1, U$3, U$100, U$101, U$103: TSOC-LOGO-SMALL; TSOC-LOGO-SML
U$102: TSOC-LOGO-LRG
UART: 4P-2.0-90D; HW4-2.0-90D
X1: 16MHZ; X3-SMD-3.6X1.3X0.8MM

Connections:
3V3: C5.2, J3.1, TSOC.11B, U1.5
5V0: 5V0.1, C3.2, C4.1, J3.3, L1.1, U1.1, U1.3
!JRST: C9.1, J4.6
!RST: C9.2, PRG.2, R6.1, U2.29
A0: TSOC.5B, U2.23
A1: TSOC.3C, U2.24
A2: TSOC.2C, U2.25
A3: R10.1, U2.26
A3E: AIO.1, R10.2
A4: I2C.2, R3.1, TSOC.10C, U2.27
A5: I2C.1, R2.1, TSOC.9C, U2.28
A6: TSOC.1C, U2.19
A7: A7.1, U2.22
AREF: A7.2, C6.2, U2.20
BYPASS1: C8.1, U1.4
D0: J4.4, R8.1, TSOC.7C, U2.30
D0E: R8.2, UART.1
D1: J4.5, R7.1, TSOC.8C, U2.31
D1E: R7.2, UART.2
D2: TSOC.6C, U2.32
D3: TSOC.5C, U2.1
D4: TSOC.4C, U2.2
D5: R9.1, TSOC.1B, U2.9
D5E: AIO.2, R9.2
D6: TSOC.2B, U2.10
D7: TSOC.3B, U2.11
D8: TSOC.4B, U2.12
D9: TSOC.6B, U2.13
D10: TSOC.7B, U2.14
D11: R5.2, TSOC.10B, U2.15
D11E: R5.1, SPI.2
D12: TSOC.9B, U2.16
D13: R4.2, R11.2, TSOC.8B, U2.17
D13E: R4.1, SPI.1
GND: AIO.4, C1.2, C2.2, C3.1, C4.2, C5.1, C6.1, C7.1, C8.2, C10.1, C11.2, C12.2, C13.2, GND.1, I2C.4, J4.1, J4.2, LED1.-, PRG.3, SPI.4, TSOC.12B, TSOC.12C, U1.2, U2.3, U2.5, U2.21, UART.4, X1.2
LEDR: LED2.-, R11.1
unnamed: LED1.+, R1.1
TSOC_5V0: L1.2, TSOC.11C
VCC: AIO.3, C1.1, C2.1, C7.2, C10.2, C11.1, C12.1, C13.1, I2C.3, J3.2, J4.3, LED2.+, PRG.1, R1.2, R2.2, R3.2, R6.2, SPI.3, U2.4, U2.6, U2.18, UART.3
XIN: U2.7, X1.3
XOUT: U2.8, X1.1

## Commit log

2016-04-09 update to Rev1.0
    [TSOC_USBUART2.brd, TSOC_USBUART2.sch]
2016-04-29 update to Rev1.1
    [TSOC_USBUART2_R1_1.brd, TSOC_USBUART2_R1_1.sch]
2016-04-30 update to Rev2.0
    [TSOC_USBUART2_R2_0.brd, TSOC_USBUART2_R2_0.sch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]
2016-05-23 update borad outline
    [TSOC_USBUART2.brd]
2016-07-10 update to V4_0
    [TSOC_USBUART2.skp, TSOC_USBUART2_R3_0.brd, TSOC_USBUART2_R3_0.sch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]
2016-07-22 update hole placements
    [TSOC_USBUART2.brd, TSOC_USBUART2.sch, TSOC_USBUART2_R1_1.brd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]
2016-12-07 update to Rev5.0
    [TSOC_USBUART2.brd, TSOC_USBUART2.sch, TSOC_USBUART2.skp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]
2017-01-14 update R5
    [TSOC_GROVEY_ONE.brd, TSOC_USBUART2.brd, TSOC_USBUART2.csv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]
2017-01-16 update documetation
    [TSOC_USBUART2_pinout.ods]

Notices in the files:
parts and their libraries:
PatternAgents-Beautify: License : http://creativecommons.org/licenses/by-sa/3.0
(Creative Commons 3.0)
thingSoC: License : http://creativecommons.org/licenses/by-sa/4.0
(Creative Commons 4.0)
